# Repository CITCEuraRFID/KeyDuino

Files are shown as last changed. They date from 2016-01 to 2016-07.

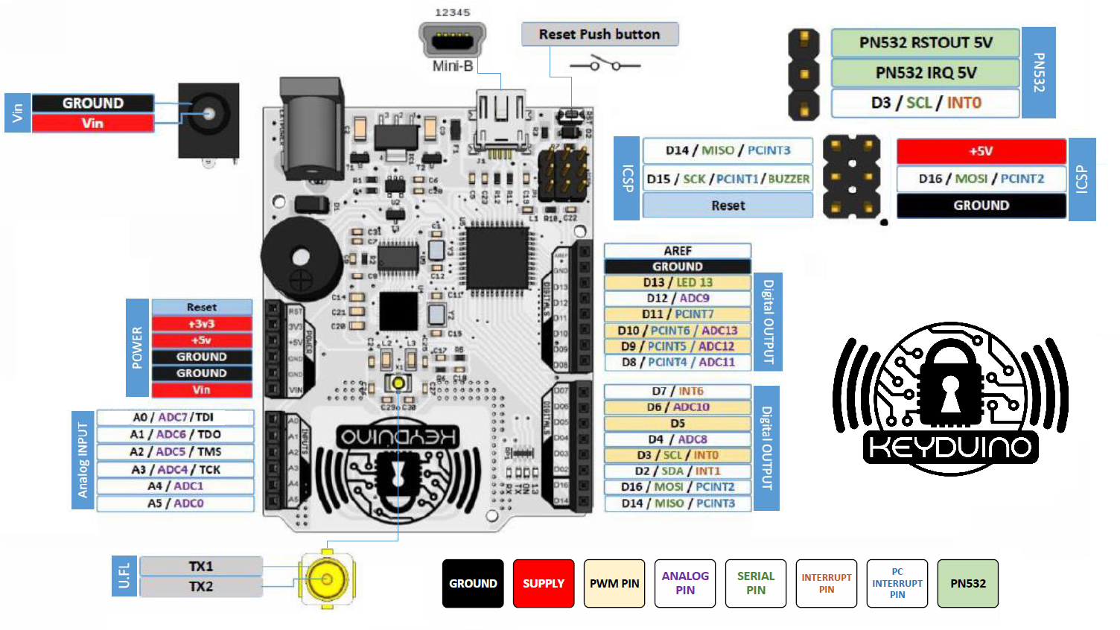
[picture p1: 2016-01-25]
hardware/KeyDuino_board/pinout KeyDuino 5.1/KeyDuino PINOUT.png

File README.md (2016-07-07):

## KeyDuino Library

Welcome to KeyDuino official GitHub repository!  
Here you will find all the files you need to develop programs for your KeyDuino.  
You can also look at the [wiki](https://github.com/CITCEuraRFID/KeyDuino/wiki) for informations about KeyDuino and its capabilities.  

The library is still under development, and everything is not perfect yet!  
That is why we would be very glad to hear from you about your experience with KeyDuino library ; if you encounter any problem, please feel free to open issues or contact us directly: that way we will be able to correct errors and improve the library.

### Tutorials & Projects
If you want to discover what you can do with your KeyDuino, join http://keyduino.forumsactifs.com/ !  
There you will find projects ideas, discussions, and tutorials, to help you get the best from your KeyDuino.  
If you have ideas to share, or questions to ask, don't hesitate! We would be very glad to hear from you.  

### Content
In this repository, you will find pretty much everything we develop for KeyDuino.

```
/---KeyDuino                  //The root folder of the repository  
|   +---KeyDuino              //The lib subfolder you need to put in your Arduino/libraries folder  
|   |   +---examples          //All the examples supplied within the lib  
|   |   |   +---projects      //Examples associated with KeyDuino projects  
|   |   |   +---NDEF          //Examples using the NDEF lib you need to download separately  
|   |   |   +---...  
|   |   |  
|   |   +---...  
|   |
|   +---KeyDuinoESP           //An implementation of KeyDuino with ESP module for WiFi communication  
|   |   +---ESP               //Files for the ESP  
|   |   +---KeyDuino          //Files for the KeyDuino  
|   |  
|   +---android_app           //The folder containing everything about Android application  
|   |   +---nfc_talker.apk    //The apk of the Android application we developped  
|   |    
|   +---hardware              //All hardware files of KeyDuino  
|   |   +---3D_printed_case   //STL files for 3D printed case
|   |   +---KeyDuino_board    //Hardware files for KeyDuino board  
|   |   +---antenna           //Hardware files for KeyDuino remote antenna  
```

### Compatibility
KeyDuino library is made to be used with [KeyDuino board](https://www.kickstarter.com/projects/1535978353/keyduino), but it also works by default with a classical Arduino Leonardo using a PN532 Shield, as long as communication is done through HSU.

### Contribution
KeyDuino library is based on Adafruit_NFCShield_I2C, with improvements by Seeed Studio, and HSU (High Speed Uart) driver added by Elechouse.

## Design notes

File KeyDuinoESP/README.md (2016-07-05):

# KeyDuinoESP
NFC enabled module in order to control authorized access via WiFi
- KeyDuino
- ESP-12

# Libraries used
- ESP8266: https://github.com/esp8266/Arduino
- MQTT: https://github.com/knolleary/pubsubclient
- KeyDuino: https://github.com/CITCEuraRFID/KeyDuino/tree/master/KeyDuino
- Streaming (print in C++): http://arduiniana.org/libraries/streaming/
- FastLED: https://github.com/FastLED/FastLED

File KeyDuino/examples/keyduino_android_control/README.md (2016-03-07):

## Dependency

This sketch is made to be used with KeyDuino mobile application, for demonstration purposes.  
It works with [bblanchon's ArduinoJson library](https://github.com/bblanchon/ArduinoJson/releases).  

If you encounter troubles using it with an older Arduino IDE version, [this ArduinoJson version](https://github.com/bblanchon/ArduinoJson/releases/download/v5.0.7/ArduinoJson-v5.0.7-old-layout.zip) may work better.  

Please note that you don't need this for NFC P2P in general ; we simply decided to use JSON to ease communication of pin numbers, etc.

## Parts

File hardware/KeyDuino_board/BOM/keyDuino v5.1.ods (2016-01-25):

Part | QTY | Value | Device | Package | Description | REF | REF ELECROW | REMARQUE
CAPACITOR
C1, C11, C12, C15 | 4 | 22pF | C-EUC0603 | C0603 | Capacitor | capacitor 0603 22pF | 2010822A
C24, C25 | 2 | 220pF | C-EUC0603 | C0603 | Capacitor | capacitor 0603 220pF
C26, C27 | 2 | 2200pF | C-EUC0603 | C0603 | Capacitor | capacitor 0603 2200pF
C18 | 1 | 1nF | C-EUC0603 | C0603 | Capacitor | capacitor 0603 1nF | 2011501A
C29, C30 | 2 | 1,2nF | C-EUC0603 | C0603 | Capacitor | Capacitor 0603 1,2nF
C5, C7, C8, C17, C22, C28, C31 | 7 | 100nF | C-EUC0603 | C0603 | Capacitor | capacitor 0603 100nF | 2013010A
C6, C9, C19, C23 | 4 | 1uF | C-EUC0603 | C0603 | Capacitor | capacitor 0603 1uF | 2013501A
C21 | 1 | 100nF | C-EUC0805 | C0805 | Capacitor | capacitor 0805 100nF
C14, C20 | 2 | 10uF | C-EUC0805 | C0805 | Capacitor | capacitor 0805 10uF | 2015010A
C2 | 1 | 10uF | CPOL-EUSMCB | SMC_B 1206 | CAPACITOR | SMC_B 1206 10uF
C3 | 1 | 22uF | CPOL-EUSMCB | SMC_B 1206 | CAPACITOR | SMC_B 1206 22uF
RESISTOR
R11, R12 | 2 | 22 | R-EU_R0603 | R0603 | RESISTOR | RESISTOR 0603 22 | 1020522A
R5 | 1 | 1.0K | R-EU_R0603 | R0603 | RESISTOR | RESISTOR 0603 1K | 1022501A
R6 | 1 | 2.7K | R-EU_R0603 | R0603 | RESISTOR | RESISTOR 0603 2,7K
R1, R2, R4, R7, R10 | 5 | 10K | R-EU_R0603 | R0603 | RESISTOR | RESISTOR 0603 10K | 1023510A
R3 | 1 | 1M | R-EU_R0805 | R0805 | RESISTOR | RESISTOR 0805 1M
RP1 | 1 | 330 | RES4NT | RES4NT | 4 Resistor Array | 4 Resistor Array 330
INDUCTOR
L1 | 1 | MH2029-300Y | WE-CBF_0805 | 805 | SMD EMI Ferrite | MH2029-300Y
L2, L3 | 2 | 560nH | INDUCTOR0805 | 0805@1 | Inductors | inductor 560nH 0805
DIODE & FUSE
D1 | 1 | M7 | DIODE-SMB | SMB | DIODE | SMB M7 (leonardo)
D2 | 1 | CD1206-S01575 | DIODE-MINIMELF | MINIMELF | DIODE | CD1206-S01575
F1 | 1 | 500mA | PTCSMD | PTC-1206 | Resettable Fuse PTC | FUSE 0805 500mA | 4060505A
CONNECTOR & MECHANICAL
ICSP | 1 | ICSP | PINHD-2X3 | 2X03 | PIN HEADER |  | 6031123A | TO SOLDER
JP1 | 1 |  | PINHD-1X3 | 1X03 | PIN HEADER |  | 6030916A | TO SOLDER
JP2 | 1 |  | PINHD-1X8CLEANBIG | 1X08-CLEANBIG | PIN HEADER |  | 6030618A | TO SOLDER
JP3 | 1 |  | PINHD-1X8CLEANBIG | 1X08-CLEANBIG | PIN HEADER |  | 6030618A | TO SOLDER
JP4 | 1 |  | PINHD-1X6CB | 1X06-CLEANBIG | PIN HEADER |  | 6030516A | TO SOLDER
JP6 | 1 |  | PINHD-1X6CB | 1X06-CLEANBIG | PIN HEADER |  | 6030516A | TO SOLDER
X1 | 1 |  | ANTENNA_U.FL | U.FL | U.FL Antenna Connector | u.FL connector | 6021031A
J1 | 1 | USB-MINI-B%C | USB-MINI-B%C | USB-MINI-B_2 |  | arduino LEONARDO | 6020522B
EXTPOWER | 1 | POWERSUPPLY_DC21MMX | POWERSUPPLY_DC21MMX | DC-21MM |  | arduino LEONARDO | 6011021A
RST | 1 | RESET | PB157 | 157SW | SKRKAEE010 | 157SW | 7020890A
BUZZ | 1 | F/QMX | F/QMX | F/QMX |  | F/QMX (3,3v) |  | TO SOLDER
LEDs
RX | 1 |  | LEDCHIPLED_0603 | CHIPLED_0603 | LED | 0603 LED yellow | 4040606A
TX | 1 |  | LEDCHIPLED_0603 | CHIPLED_0603 | LED | 0603 LED RED | 4040506A
ON | 1 |  | LEDCHIPLED_0603 | CHIPLED_0603 | LED | 603 LED green | 4040706A
13 | 1 |  | LEDCHIPLED_0603 | CHIPLED_0603 | LED | 603 LED blue | 4040806A
IC
U1 | 1 | ATMEGA32U4-XUAU | ATMEGA32U4-XUAU | TQFP44-PAD | ATMEGA32U4-XUAU | ATMEGA32U4-XUAU
U2 | 1 | LP2985-33DBVR | LP2985-XXDBVR33 | SOT23-DBV | ULTRALOW-POWER REGULATORS | LP2985-33DBVR
IC1 | 1 | NCP1117ST50T3G | MC33269ST-3.3T3 | SOT223 | Regulator 800 mA | NCP1117ST50T3G |  | 117-5
U3 | 1 |  | TXB0108PWR | TSSOP20 | 8-Bit Bi-Directional Level Shifter | TXB0108PWR
U4 | 1 | PN532 | PN532 | HVQFN40-6X6 | PN532 - Near Field Communication (NFC) controller | PN532
CRYSTAL
Y2 | 1 | 27.12MHz | CRYSTALTHIN | CRYSTAL_3.2X2.5 | Crystals | 7B-27,1200MAAJ-T
Y3 | 1 | 16MHz KX-7 | CRYSTAL-3.2-2.5 | CRYSTAL-3.2-2.5 |  | 16MHz KX-7
MOSFET
T1 | 1 | PMV48XP | PMOSSOT23 | SOT-23 | MOS FET | PMV48XP
T2 | 1 | FDN340P | PMOSSOT23 | SOT-23 | MOS FET | FDN340P
T3 | 1 | BSS123 | PMOSSOT23 | SOT-23 | MOS FET | BSS123
CABLE USB MINI MALE
2 x 2,54mm jumpers

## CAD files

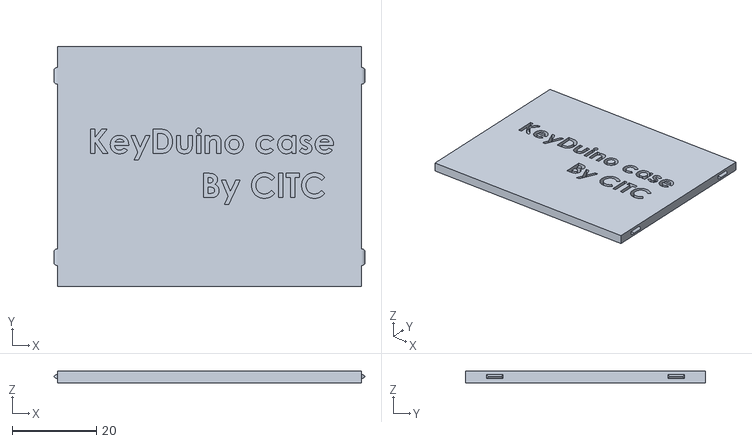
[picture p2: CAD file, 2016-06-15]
hardware/3D_printed_case/charlier_case/top KeyDuino case.STL
73.7 x 57.0 x 2.80

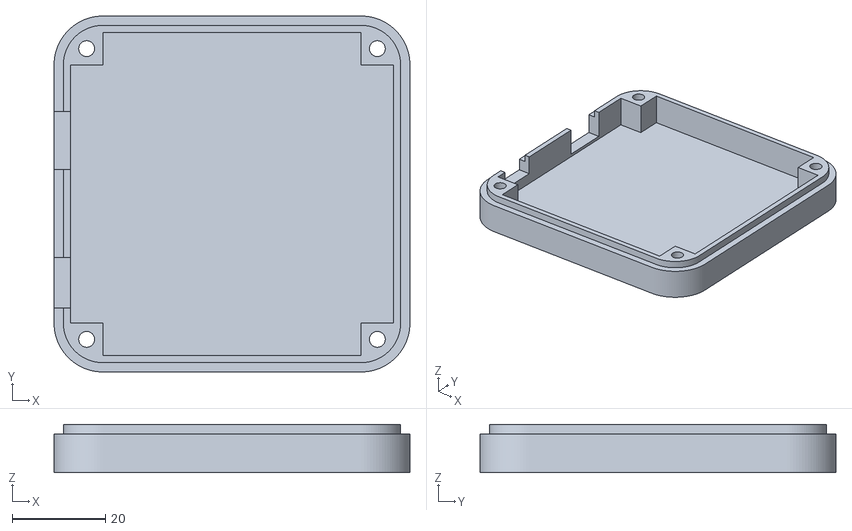
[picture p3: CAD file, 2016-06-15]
hardware/3D_printed_case/ray_case/leonardo_case_base_v1_2_ray_bin.stl
76.3 x 76.3 x 10.3

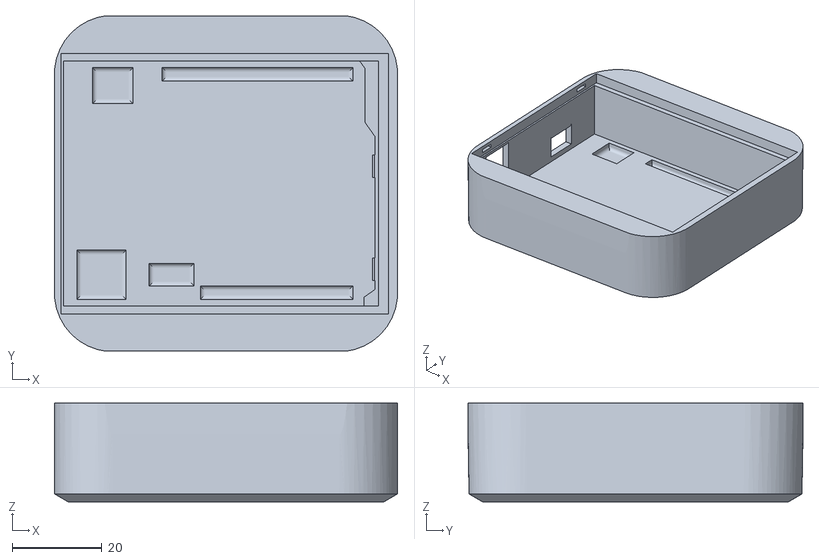
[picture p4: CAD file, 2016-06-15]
hardware/3D_printed_case/charlier_case/KeyDuino case5.STL
76.5 x 74.6 x 22.0

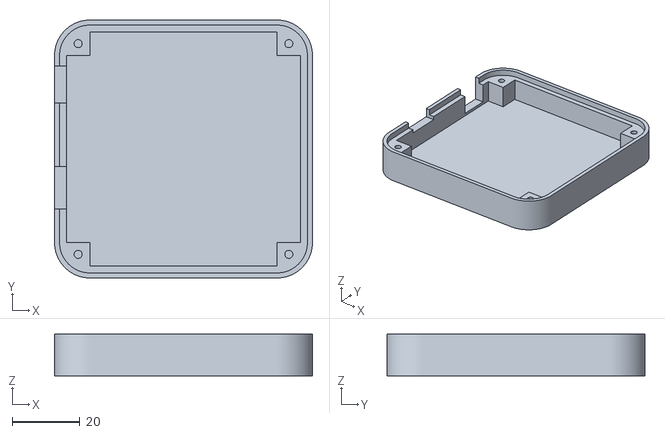
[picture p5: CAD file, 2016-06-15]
hardware/3D_printed_case/ray_case/leonardo_case_lid_v1_2_ray.stl
76.3 x 76.3 x 12.3

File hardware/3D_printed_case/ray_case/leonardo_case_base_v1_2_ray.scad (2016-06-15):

//  ----------------------------------------------------------------------- LICENSE
//  This "3D Printed Case for Arduino Uno, Leonardo" by Zygmunt Wojcik is licensed
//  under the Creative Commons Attribution-ShareAlike 3.0 Unported License.
//  To view a copy of this license, visit
//  http://creativecommons.org/licenses/by-sa/3.0/
//  or send a letter to Creative Commons, PO Box 1866, Mountain View, CA 94042, USA.


include <leonardo_case_param_v1_2.scad>

//------------------------------------------------------------------------- MODULES
module pcbLeg() {		
	translate([0, 0, 0])
	difference() { 											
		cylinder(h = floorHeight + pcbPositionZ, r1=5.5/2, r2 = 4.5/2);
	}
}


//------------------------------------------------------------------------- MAIN BLOCK
difference()
{
																		// ADD
	union()
	{
		// Add Base
		linear_extrude(height = height/2, convexity = 10)
		minkowski()
		{									
			square([width, wide], center = true);
			circle(roundR);
		}
	}
																		// SUBSTRACT
	union()
	{
		// Lift floor height
		translate([0, 0, floorHeight])
		{
			// Cut Base hole
			linear_extrude(height = height/2, convexity = 10)
			minkowski()
			{
				square([width, wide], center = true);
				circle(roundR - pillarSize);
			}
			// Cut upper block lock
			difference() {
				translate([0, 0, height/2 - floorHeight - blockLockSize]) {
					cylinder(h = blockLockSize+gap, r=width);
				}
				translate([0, 0, height/2 - floorHeight - blockLockSize - gap*2]) {
					linear_extrude(height = blockLockSize+gap*4, convexity = 10)
					minkowski() {
						square([width, wide], center=true);
						circle(roundR - layerWidth*4);
					}
				}
			}
			// Cut x panels 
			for (i = [0 : 180 : 180])				
			rotate([0, 0, i])
			translate([width/2 + roundR - pillarSize/2 - layerWidth*7, 0, 0])
			{
				// Cut X panel hole
				translate([0, 0, height/2])
				cube([pillarSize, sidePanelXWidth, height], center=true);
                
				// Cut X, Y srew holes
				for (i = [wide/2, -wide/2])
				{
					translate([-(roundR - pillarSize/2 - layerWidth*7), i, - floorHeight])
					if (i>0) 
					{
						rotate([0, 0, 45])
						translate([screwHoleRoundR, 0, 0])
						{
							cylinder(h = height*2, r=screwExt/2, center=true);
							cylinder(h = 5,
                                    r1 = (screwHead + (screwHead - screwExt))/2,
                                    r2 = screwExt/2, center=true);
						}
					}
					else
					{
						rotate([0, 0, -45])
						translate([screwHoleRoundR, 0, 0])
						{
							cylinder(h = height*2, r=screwExt/2, center=true);
							cylinder(h = 5,
                                    r1 = (screwHead + (screwHead - screwExt))/2,
                                    r2 = screwExt/2, center=true);
						}
					}
				}
			}
			// Cut Y panels 
			for (i = [90 : 180 : 270])
			rotate([0, 0, i])
			translate([wide/2 + roundR - pillarSize/2 - layerWidth*7, 0, 0])
			{
				// Cut Y panel hole
				translate([0, 0, height/2])
				cube([pillarSize, sidePanelYWidth, height], center=true);
			}
			
            // Cut USB and Power holes
			// translate to pcb position
			translate([-pcbPositionX, -pcbWide/2, pcbPositionZ + pcbHeight])
			{
				// cut power hole
				translate([0, powerJackPosition, (powerJackHeight-2)/2])
				cube([10, powerJackWide, powerJackHeight], center=true);
				// cut usb hole
				translate([0, usbHolePosition, 1.3])
				cube([10, usbWide, usbHeight], center=true);
			}
		}
	}
}
//------------------------------------------------------------------------- ADD PCB LEGS
// Translate to pcbPositionX	
translate([-pcbPositionX, -pcbWide/2, 0])

difference()
{
																		// ADD
	union()
	{
		
	}
																		// SUBSTRACT
	union()
	{
		//
	}
}

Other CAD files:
hardware/3D_printed_case/ray_case/leonardo_case_lid_v1_2_ray.scad

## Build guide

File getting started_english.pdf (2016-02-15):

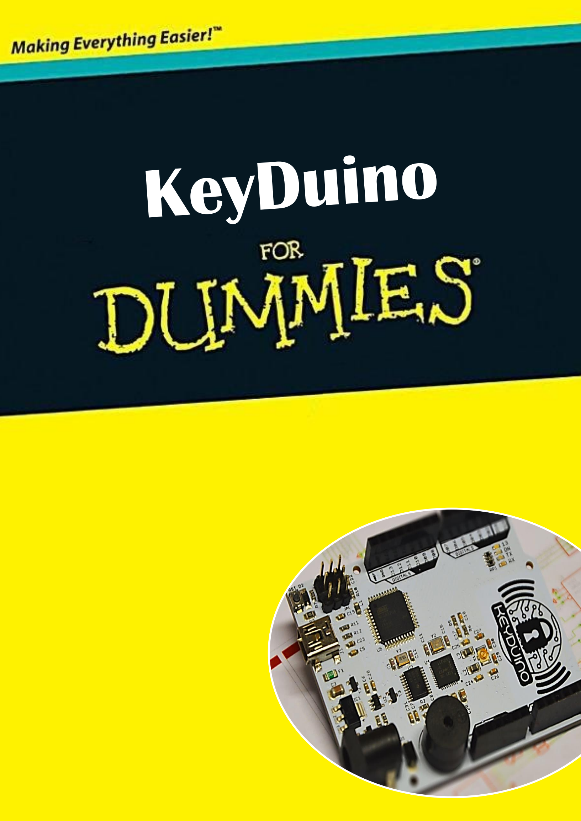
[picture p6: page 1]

## Introduction

KeyDuino is a NFC development platform which allows quick and easy creation of prototypes. This card is not a finished product for a defined application but can be adapted to different projects while adding specific material equipment and security software.

Therefore, you should pay attention to the liability and protection of your own developments on the platform. They are utterly under your responsibility, and so is the usage of the application you will develop.

This document provides key points you will need to realize your projects.

KeyDuino is a powerful tool and we all must ensure that its use respects the values that led to its creation. By this we mean the values of a community of geeks/makers but also responsible people aiming at developing and sharing innovative projects, competences and good ideas.

Hence, don’t forget that hacking attempts on systems that don’t belong to you are against the spirit of KeyDuino. Moreover, remember that alone we are faster, but together we go further!

### KeyDuino Team

# 1) Initialize your KeyDuino

### Install Arduino environment

To start using and program your KeyDuino, you require the Arduino development environment (IDE). You may download it there:
https://www.arduino.cc/en/Main/Software Current developments are made under Arduino version 1.6.5. If you are a new Arduino developer, we advise you to use that same version to avoid troubles.
Unzip the file and install Arduino.

### Download KeyDuino library

To get access to KeyDuino code samples and library, you first have to download it on GitHub platform:
https://github.com/CITCEuraRFID/KeyDuino Click the « Download ZIP » button, and once the download is complete, extract it. In KeyDuino directory, you will find different folders. Simply copy the KeyDuino subfolder and paste it in your Arduino libraries directory. The library is now installed! You can then start Arduino IDE and use it.

### Getting KeyDuino Android application

We have developed an Android application to experiment exchanges with smartphones. You can find the APK file in KeyDuino directory.
We will soon add the sources in the GitHub repository too.
Remind yourself that current Apple iPhones are not compatibles with KeyDuino or NFC tags.

### Install KeyDuino drivers

Connect KeyDuino board to your computer with the supplied cable. « On » LED should light.

- Windows
For Microsoft Windows :
http://www.visualmicro.com/post/2012/06/02/Arduino-Leonardo-Windows-Hardware-USB-Installation-Guide.aspx (http://www.visualmicro.com/post/2012/06/02/Arduino-Leonardo-Windows-Hardware-USB-Installation-Guide.aspx)
- Linux
Connect the board. That's all.
- Mac OS
The first time you connect the board on a Mac OS system, the « Keyboard Setup Assistant » should open. Just shut the window, you don't have anything to configure.

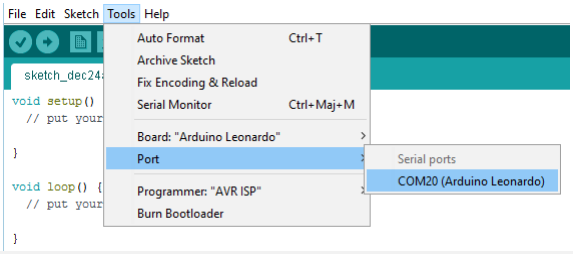
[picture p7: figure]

Error : you’re getting the following error message

Check if selected com port is still the same. Sometimes, the port disconnect and change. Then try again. If the problem persists, disconnect the board, shut the monitor, reconnect the board and retry.

Error: the port isn't detected

Solution 1: Disconnect your KeyDuino, close the IDE. Reconnect the board and retry selecting the port. Solution 2 : Re-install the drivers, and check if KeyDuino is recognized by your computer.

# 2) Get started with your KeyDuino

### Identify a tag

In the IDE, select the port your board is plugged to. The board should be identified as a Arduino Leonardo.

Hopefully, the default sketch on the board will allow to read NFC tags and display its ID. To get the informations, click on « Serial Monitor » button.

For this example, your selected baudrate must be 115200 Bauds. By default, if you just downloaded the IDE, it will probably be 9600 ; just change it in the Serial Monitor. Now, take the supplied NFC tag and approach it from KeyDuino antenna ; you should hear a « bip » sound when the board detects it.

Reading antenna

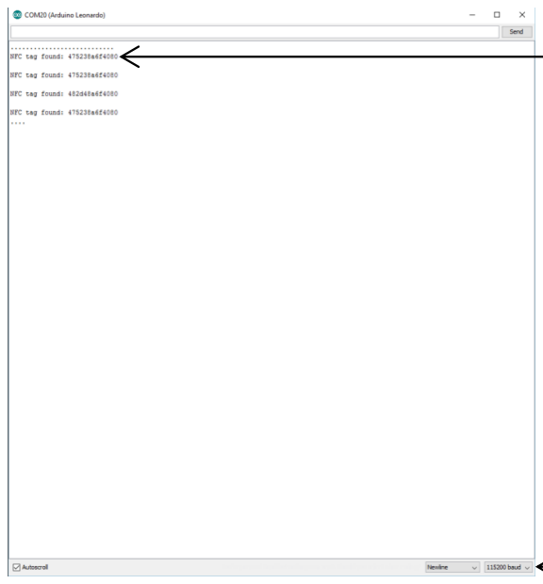
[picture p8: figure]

Error: nothing happens

Solution 1: Try with the other tag. Si that one is working, please contact us for replacement of the deficient tag. Solution 2: Take away KeyDuino board from any metallic surface during reading.
Solution 3: Try with example PN532_TEST ; if you hear no sound, please contact us (). If you hear a sound, try programming the board with tag_identification example (see below).

### (Optionnal) Connecting the antenna

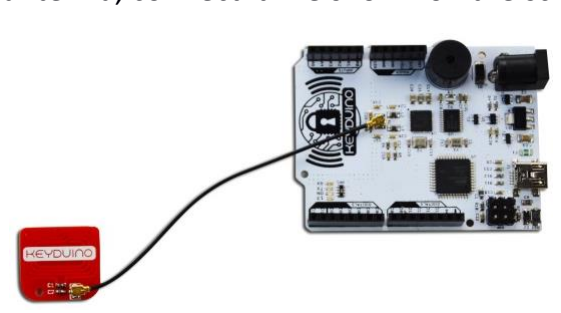
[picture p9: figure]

If you ordered a separate antenna, connect it like shown on the schematic below. You should hear a « click ».

### You are now ready to use your KeyDuino!

Baudrate

Tag ID

Advice:

- Try to not bend the cable
- Don't connect and disconnect the cable too often for it is quite fragile. Take care of it.
- Avoid putting it through metallic material
- Like integrated antenna, do not put it in contact with metal
- Use plastic screws rather than metallic ones to fix the antenna
- Note that superglue and double-sided tape work fine!

# Annexe 1 : schematics

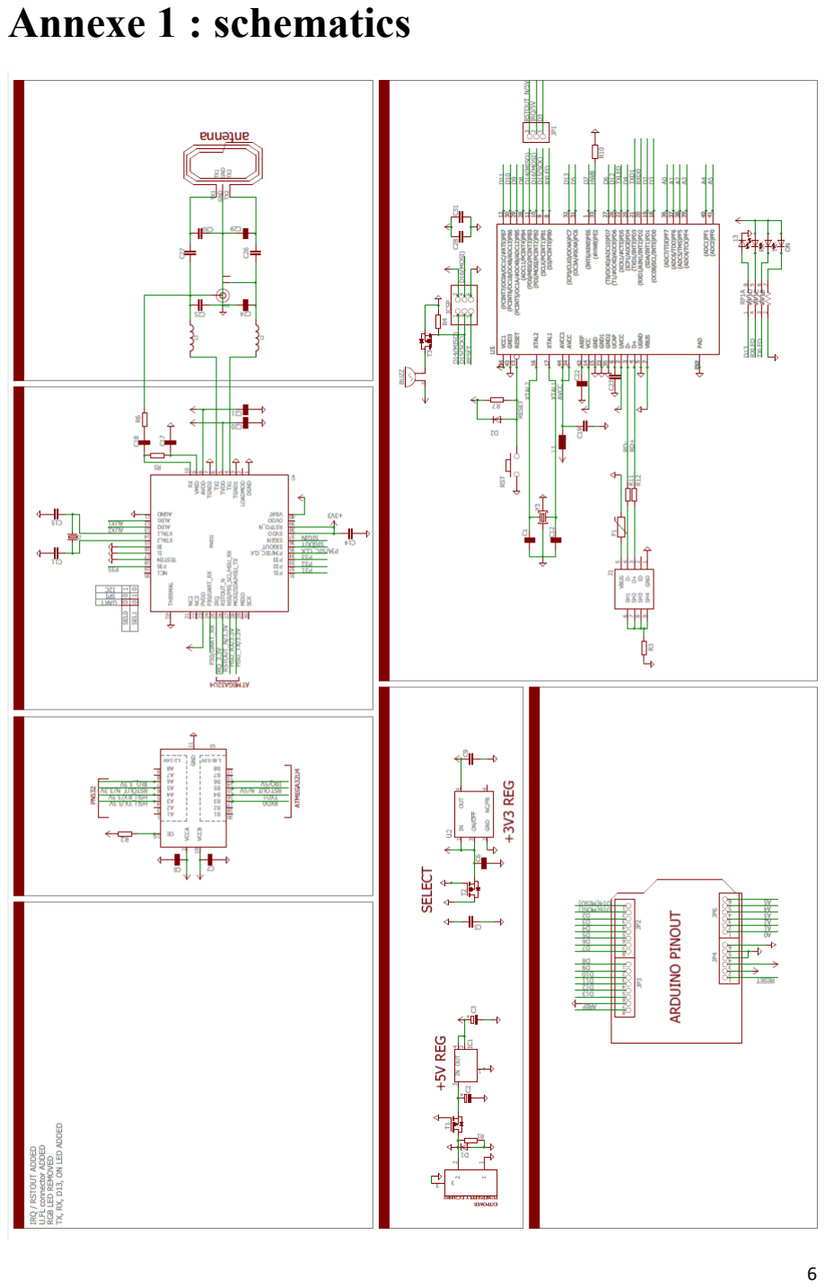
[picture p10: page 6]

# Annexe 2 : layout

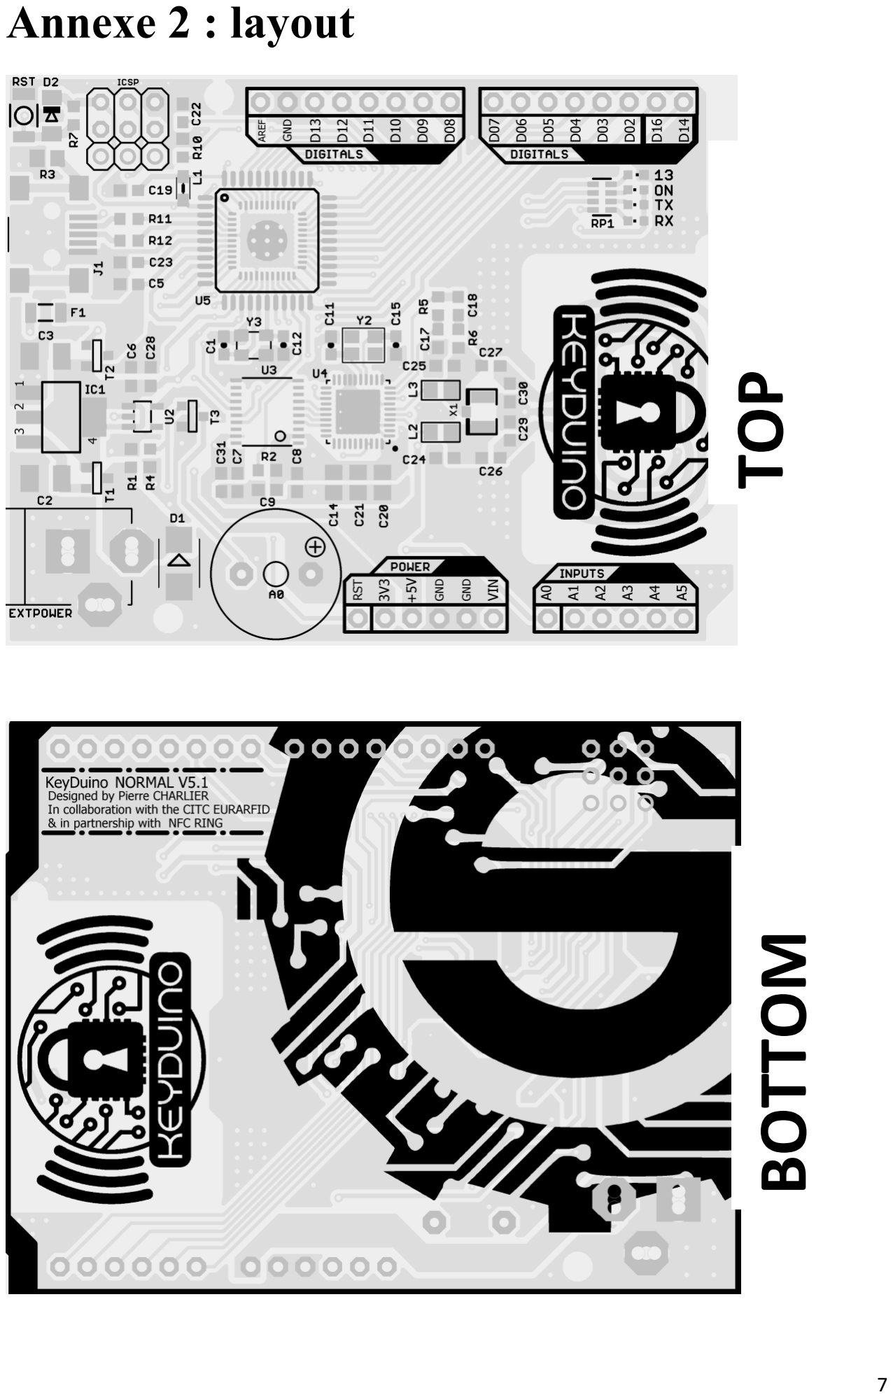
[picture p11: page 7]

# TOP BOTTOM

# Annexe 3 : BOM (Bill Of Material)

Part | QTY | Value | Device | Package | Description | REF

CAPACITOR

C1, C11, C12, C15 | 4 | 22pF | C-EUC0603 | C0603 | Capacitor | capacitor 0603 22pF
C24, C25 | 2 | 220pF | C-EUC0603 | C0603 | Capacitor | capacitor 0603 220pF
C26, C27 | 2 | 2200pF | C-EUC0603 | C0603 | Capacitor | capacitor 0603 2200pF
C18 | 1 | 1nF | C-EUC0603 | C0603 | Capacitor | capacitor 0603 1nF
C29, C30 | 2 | 1,2nF | C-EUC0603 | C0603 | Capacitor | Capacitor 0603 1,2nF
C5, C7, C8, C17, C22, C28, C31 | 7 | 100nF | C-EUC0603 | C0603 | Capacitor | capacitor 0603 100nF
C6, C9, C19, C23 | 4 | 1uF | C-EUC0603 | C0603 | Capacitor | capacitor 0603 1uF
C21 | 1 | 100nF | C-EUC0805 | C0805 | Capacitor | capacitor 0805 100nF
C14, C20 | 2 | 10uF | C-EUC0805 | C0805 | Capacitor | capacitor 0805 10uF
C2 | 1 | 10uF | CPOL-EUSMCB | SMC_B 1206 | CAPACITOR | SMC_B 1206 10uF
C3 | 1 | 22uF | CPOL-EUSMCB | SMC_B 1206 | CAPACITOR | SMC_B 1206 22uF

RESISTOR

R11, R12 | 2 | 22 | R-EU_R0603 | R0603 | RESISTOR | RESISTOR 0603 22
R5 | 1 | 1.0K | R-EU_R0603 | R0603 | RESISTOR | RESISTOR 0603 1K
R6 | 1 | 2.7K | R-EU_R0603 | R0603 | RESISTOR | RESISTOR 0603 2,7K
R1, R2, R4, R7, R10 | 5 | 10K | R-EU_R0603 | R0603 | RESISTOR | RESISTOR 0603 10K
R3 | 1 | 1M | R-EU_R0805 | R0805 | RESISTOR | RESISTOR 0805 1M
RP1 | 1 | 330 | RES4NT | RES4NT | 4 Resistor Array | 4 Resistor Array 330

INDUCTOR

L1 | 1 | MH2029-300Y | WE-CBF_0805 | 805 | SMD EMI Ferrite | MH2029-300Y
L2, L3 | 2 | 560nH | INDUCTOR0805 | 0805@1 | Inductors | inductor 560nH 0805

DIODE & FUSE

D1 | 1 | M7 | DIODE-SMB | SMB | DIODE | SMB M7 (leonardo)
D2 | 1 | CD1206-S01575 | DIODE-MINIMELF | MINIMELF | DIODE | CD1206-S01575
F1 | 1 | 500mA | PTCSMD | PTC-1206 | Resettable Fuse PTC | FUSE 0805 500mA

CONNECTOR & MECHANICAL

ICSP | 1 | ICSP | PINHD-2X3 | 2X03 | PIN HEADER
JP1 | 1 | | PINHD-1X3 | 1X03 | PIN HEADER
JP2 | 1 | | PINHD-1X8CLEANBIG | 1X08-CLEANBIG | PIN HEADER
JP3 | 1 | | PINHD-1X8CLEANBIG | 1X08-CLEANBIG | PIN HEADER
JP4 | 1 | | PINHD-1X6CB | 1X06-CLEANBIG | PIN HEADER
JP6 | 1 | | PINHD-1X6CB | 1X06-CLEANBIG | PIN HEADER
X1 | 1 | | ANTENNA_U.FL | U.FL | U.FL Antenna Connector | u.FL connector
J1 | 1 | USB-MINI-B%C | USB-MINI-B%C | USB-MINI-B_2
EXTPOWER | 1 | POWERSUPPLY_DC21MMX | POWERSUPPLY_DC21MMX | DC-21MM
RST | 1 | RESET | PB157 | 157SW | SKRKAEE010 | 157SW
BUZZ | 1 | F/QMX | F/QMX | F/QMX | | F/QMX (3,3v)

LEDs

RX | 1 | LEDCHIPLED_0603 | CHIPLED_0603 | LED | 0603 LED yellow
TX | 1 | LEDCHIPLED_0603 | CHIPLED_0603 | LED | 0603 LED RED
ON | 1 | LEDCHIPLED_0603 | CHIPLED_0603 | LED | 603 LED green
13 | 1 | LEDCHIPLED_0603 | CHIPLED_0603 | LED | 603 LED blue

IC

U1 | 1 | ATMEGA32U4-XUAU | ATMEGA32U4-XUAU | TQFP44-PAD | ATMEGA32U4-XUAU | ATMEGA32U4-XUAU
U2 | 1 | LP2985-33DBVR | LP2985-XXDBVR33 | SOT23-DBV | ULTRALOW-POWER REGULATORS | LP2985-33DBVR
IC1 | 1 | NCP1117ST50T3G | MC33269ST-3.3T3 | SOT223 | Regulator 800 mA | NCP1117ST50T3G
U3 | 1 | | TXB0108PWR | TSSOP20 | 8-Bit Bi-Directional Level Shifter | TXB0108PWR
U4 | 1 | PN532 | PN532 | HVQFN40-6X6 | PN532 – NFC controller | PN532

CRYSTAL

Y2 | 1 | 27.12MHz | CRYSTALTHIN | CRYSTAL_3.2X2.5 | Crystals | 7B-27,1200MAAJ-T
Y3 | 1 | 16MHz KX-7 | CRYSTAL-3.2-2.5 | CRYSTAL-3.2-2.5 | | 16MHz KX-7

MOSFET

T1 | 1 | PMV48XP | PMOSSOT23 | SOT-23 | MOS FET | PMV48XP
T2 | 1 | FDN340P | PMOSSOT23 | SOT-23 | MOS FET | FDN340P
T3 | 1 BSS123 | PMOSSOT23 | SOT-23 | MOS FET | BSS123

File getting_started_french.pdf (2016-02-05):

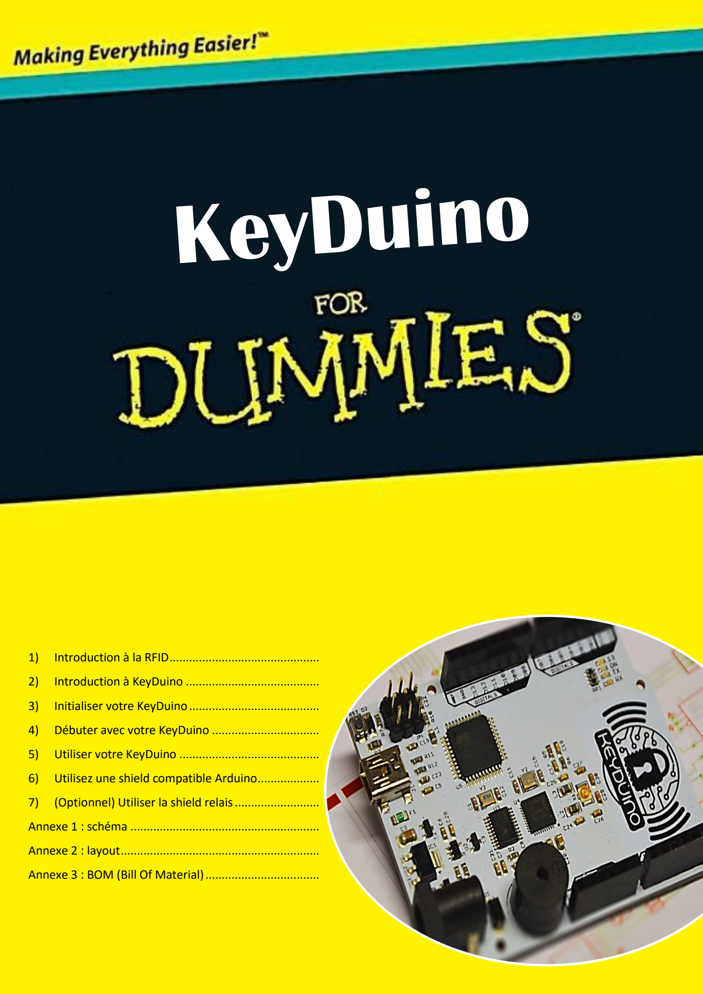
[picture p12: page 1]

1) Introduction à la RFID |
2) Introduction à KeyDuino |
3) Initialiser votre KeyDuino |
4) Débuter avec votre KeyDuino |
5) Utiliser votre KeyDuino |
6) Utilisez une shield compatible Arduino |
7) (Optionnel) Utiliser la shield relais |
Annexe 1 : schéma |
Annexe 2 : layout |
Annexe 3 : BOM (Bill Of Material) |

## Avertissements

KeyDuino est une plateforme de développement NFC qui permet de créer facilement et rapidement des prototypes. Cette carte ne consiste pas en un produit terminé pour telle ou telle application et nécessite en fonction du projet à réaliser d’y ajouter des équipements matériels ou logiciels à sécuriser

À ce titre, la question de la fiabilité et de la protection de vos développements à partir de la plateforme est importante et est de votre entière responsabilité, au même titre que l’usage des applications que vous développerez.

Par ce document, nous vous apportons quelques clefs nécessaires au bon fonctionnement de vos projets.

KeyDuino peut être un outil puissant, c’est pourquoi il nous revient collectivement de respecter, lors de son utilisation, les valeurs qui ont mené à sa création : la création d’une communauté de bidouilleurs/geeks/passionnés et surtout responsables s’attachant à développer des projets sympathiques, à partager les compétences et bonnes idées

Dès lors, n’oubliez pas que les tentatives de hack sur des systèmes ne vous appartenant pas vont à l’encontre de « l’état d’esprit KeyDuino ». et que seul on va plus vite mais ensemble, on va plus loin !

### KeyDuino Team

# 1) Introduction à la RFID

### Présentation globale

La RFID (Radio Frequency Identification) est une technologie bien implantée dans de nombreux secteurs. Cette technologie existe depuis les années 1970, mais s'est surtout développée à la fin des années 1990.

Les systèmes utilisant la RFID sont composés de deux parties : un lecteur, qui va venir apporter l’énergie, et un transpondeur (un tag).
Ces derniers communiquent par liaison radio fréquences.

On distingue 3 catégories d’applications :
- La RFID LF (Low Frequency) : de 125 à 135 kHz et ayant une portée de moins de 10 centimètres. Elle est principalement utilisée dans les badges d’accès.
- La RFID HF (High Frequency) : sur une fréquence de 13,56 MHz. La RFID HF est notamment utilisée dans les passeports biométriques et sert de base à la technologie NFC (Near Field Communication) présente dans de très nombreux produits.
- La RFID UHF (Ultra High Frequency): en Europe, sa fréquence est de 868 MHz. La portée est étendue à une dizaine de mètres. Cette technologie est notamment utilisée pour la traçabilité en logistique, ainsi que pour dresser des inventaires.

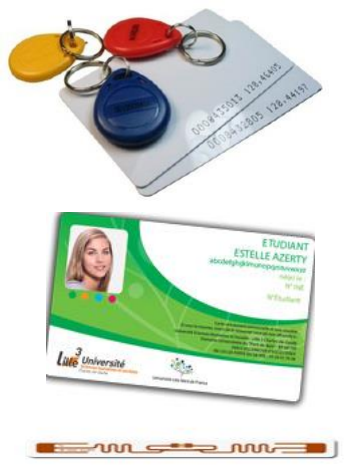
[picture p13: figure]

La structure d’un transpondeur est extrêmement simple. Il s’agit uniquement d’une antenne reliée à une puce.

Le lecteur se couple au transpondeur et envoie de l’énergie au transpondeur dont le processeur est alors alimenté.
Dans ce document, nous parlerons uniquement de tags passifs (non alimentés de

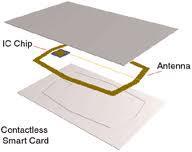
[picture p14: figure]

façon interne).

En termes de couplage, il en existe deux types;
- le couplage magnétique (H) dans le cas d’un champ dit proche (de quelques centimètres à 1.5m). Les fréquences utilisées sont les LF et HF. Les antennes sont alors constituées de boucles inductives.
- le couplage électrique (E) pour le champ dit lointain (jusqu’à 6 mètres).
Les fréquences en jeux sont l’UHF. Les antennes sont alors des dipôles ou des patchs.

### La NFC

La NFC, ou Near Field Communication (Communication en Champ Proche), est une technologie standardisée de communication sans-fil à courte portée, permettant des transactions, de l'échange de données numériques, et la connexion d'appareils électroniques par un simple contact. La NFC est compatible avec des centaines de millions de smartphones, cartes sans-contact, et lecteurs déjà déployés dans le monde entier.

# 2) Introduction à KeyDuino

### Généralités sur KeyDuino

KeyDuino est une carte électronique programmable utilisant l’environnement Arduino (une plateforme de développement open source) et permettant de créer des interactions avec la technologie NFC.
Il est possible d’imaginer de nombreux scénarios d’utilisation des cartes KeyDuino dans de multiples domaines (transfert d’informations par NFC, identification sur une chaine de production,…). :

L’objectif principal de KeyDuino est de proposer une solution de prototypage rapide, plus spécifiquement dans le domaine de la sécurité. En effet, grâce aux nombreuses entrées sorties (E/S) dont disposent les cartes, connecter un actionneur, mécanique par exemple, est une chose facile. Dès lors, interagir sur une gâche de fermeture de porte, un verrou électronique, un starter de voiture, (…), est possible.
La technologie NFC prend tout son intérêt dans ce type d’applications. La lecture en champs proche permet d’opter pour une identification par carte, par badge et surtout via une bague NFC ou un smartphone.

### Architecture globale de KeyDuino

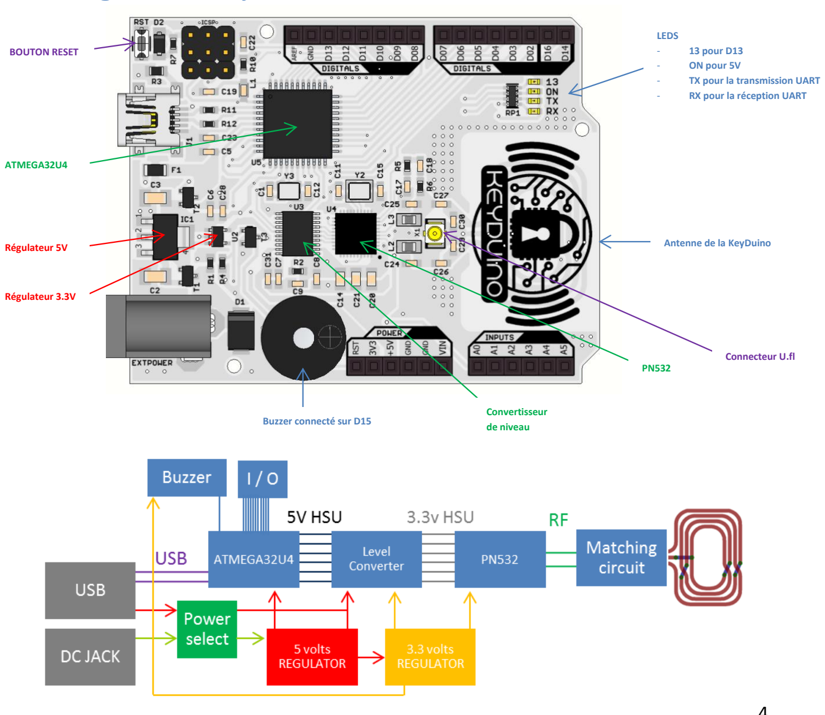
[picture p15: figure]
LEDS - 13 pour D13 - ON pour 5V - TX pour la transmission UART - RX pour la réception UART; Antenne de la KeyDuino; Buzzer connecté sur D15; ATMEGA32U4; Convertisseur de niveau; Connecteur U.fl; BOUTON RESET; Régulateur 5V; Régulateur 3.3V

### Pinout de KeyDuino

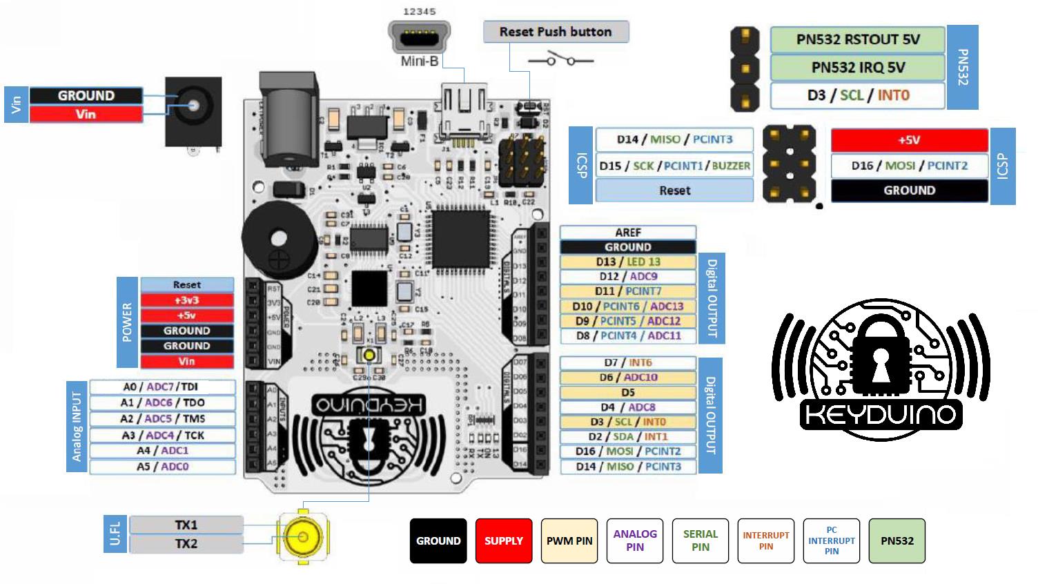
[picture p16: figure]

Alimentations
- Alimentation 5v
- Alimentation 3.3v
- Entrée d’alimentation VIN (pin ou connecteur)
- Sélection automatique entre VIN et l’alimentation 5volts Entrée/sorties
- 21 entrées sorties utilisables (A0-A5 & D2/D15)
- 7 PWM (D3, D5, D6, D9, D10, D11, D13)
- 12 entrées (A0-A5 & D4, D6, D8, D9, D10, D12) Communications
- Software UART
- Software SPI
- I2C
Processeur
- ATMEGA32U4
- mémoire flash disponible : 28KB
- SRAM : 2.5KB
- EEPROM : 1KB
- Fréquence 16Mhz
NFC
- PN532 connecté en HSU
- IRQ accessible
- RSTOUT accessible
- Connecteur U.fl lié à TX1, TX2

### Fréquence en jeu

Connaitre la fréquence de fonctionnement de KeyDuino va vous permettre de comprendre quel type de tags la carte pourra lire et ceux avec lesquelsi il sera impossible de communiquer.

Pour ce faire, observons un peu la forme de l’antenne de la KeyDuino :

Comme vous pouvez le constater, il s’agit d’une bobine constituée d’un ensemble de boucles inductives (4 boucles). KeyDuino utilise donc (principalement) le champ magnétique E pour communiquer avec les tags en champ proche.
Pour préciser, l’antenne de KeyDuino et son circuit d’accord sont calibrés pour une fréquence de 13.56Mhz, soit la fréquence de la RFID HF (excluant de fait la lecture de tags LF ou UHF).

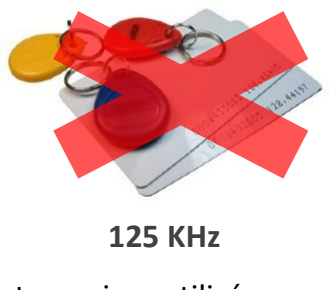
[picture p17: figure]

Le tranceiver utilisé pour permettre la lecture des tags est un PN532 connecté en HSU (High Speed Uart). Ce module supporte 7 modes d’opérations différents :

- ISO/IEC 14443A/MIFARE Reader/Writer
- FeliCa Reader/Writer
- ISO/IEC 14443B Reader/Writer
- ISO/IEC14443A/MIFARE Card MIFARE Classic 1K
- MIFARE Classic 4K card emulation mode
- FeliCa Card emulation
- ISO/IEC 18092, ECMA 340 Peer-to-Peer

### Métal et KeyDuino

Le champ magnétique de la NFC ne peut fonctionner à travers le métal. Par conséquent, il est impossible de lire un tag à travers n’importe quel élément métallique via la KeyDuino ou une antenne déportée.

125 KHz | 13.56 MHz | 868 MHz

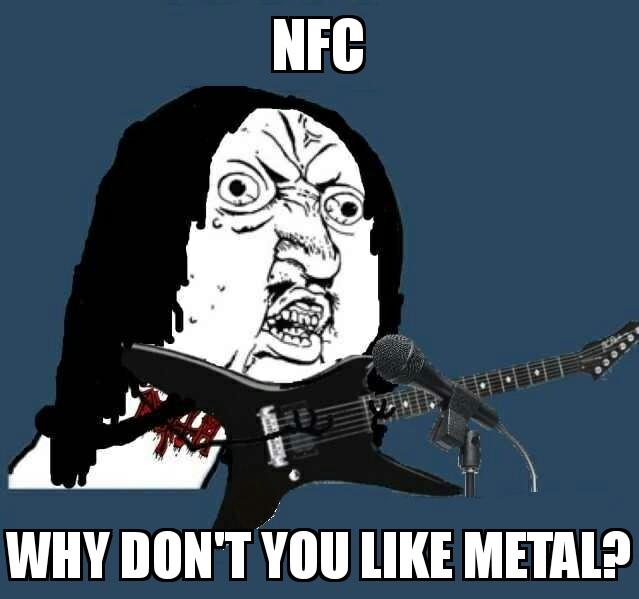
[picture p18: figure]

### Détruire correctement votre KeyDuino

KeyDuino vous permettra de prototyper bon nombre de projets. Néanmoins, dans la précipitation, certaines erreurs classiques peuvent endommager, voire détruire votre KeyDuino.
Voici une liste non-exhaustive des erreurs potentielles :

Court circuits :
- Faire un court-circuit entre une entrée/sortie et la masse/l’alimentation
- Faire un court-circuit entre deux entrées/sorties avec chacune un état différent
- Faire un court-circuit entre l’alimentation 5v/3.3v/VIN et la masse

Surtension :
- Appliquer une tension supérieure à 5.5volts sur une entrée/sortie
- Appliquer une tension supérieure à 5 volts sur la pin 5volts
- Appliquer une tension supérieure à 12 volts sur la pin 12 volts / le connecteur DC

Surconsommation :
- Consommer plus de 40mA par pin
- Consommer plus de 200mA sur l’ensemble des pins
- Consommer plus de 2A sur l’alimentation VIN
- Consommer plus de 500mA sur l’alimentation 5volts
- Consommer plus de 150mA sur l’alimentation 3.3volts

Etonnamment, KeyDuino n’est pas prévu pour fonctionner à des températures extrêmes, des milieux trop humides ou sous des chocs trop importants. Des erreurs classiques telles que mesurer les vibrations à l’intérieur d’un mixer ou la température dans un four peuvent laisser quelques dommages à KeyDuino.

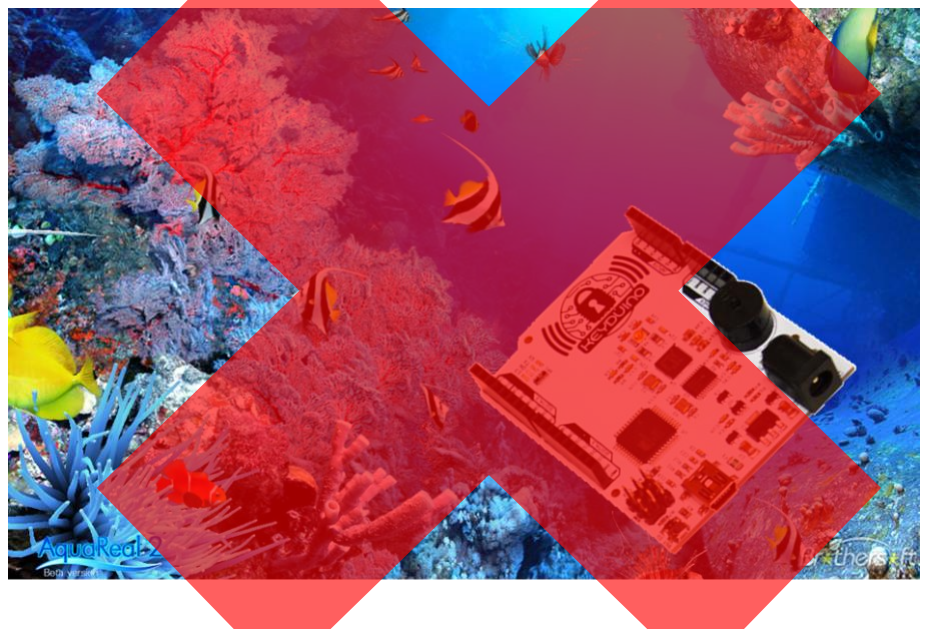
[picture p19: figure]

### Prenez donc soin de votre KeyDuino !

# 3) Initialiser votre KeyDuino

### Installer l’environnement Arduino

Pour commencer à utiliser et programmer votre KeyDuino, vous aurez besoin de l’environnement de développement (IDE) Arduino. Vous pouvez le télécharger ici : https://www.arduino.cc/en/Main/Software Les codes actuels sont développés avec la version 1.6.5 d’Arduino. Si vous débutez avec Arduino, il est recommandé d’utiliser la même version pour éviter tous problèmes.
Décompressez le fichier et installez Arduino.

### Télécharger la bibliothèque KeyDuino

Pour avoir accès aux codes d’utilisations et à la bibliothèque KeyDuino, il faut premièrement la télécharger sur la plateforme GitHub :
https://github.com/CITCEuraRFID/KeyDuino Cliquer sur le bouton « Download ZIP », et une fois téléchargé, l’extraire. Dans le répertoire KeyDuino, vous trouverez divers dossiers, comme hardware, qui contient les schémas électroniques notamment. Copiez simplement le sous-dossier KeyDuino, et collez le dans le répertoire « libraries » d’Arduino.
La bibliothèque est alors installée ! Il n’y a plus qu’à lancer l’IDE Arduino pour pouvoir l’utiliser.

### Télécharger l’application KeyDuino

Pour utiliser l’application Android développée spécialement pour KeyDuino, télécharger l’apk sur la plateforme GitHub.
Vous pouvez également trouver les sources de cette application dans le dossier de la bibliothèque KeyDuino précédemment téléchargé.
Signalons que bien malheureusement, les Apple iPhones ne sont pas compatibles avec KeyDuino ou les tags NFC dans leurs versions actuelles.

### Installer les drivers KeyDuino

Connectez la KeyDuino à un port USB avec le câble fourni. La LED « On » doit s’allumer.

- Windows
Pour Microsoft Windows XP / Seven : http://www.visualmicro.com/post/2012/06/02/Arduino-Leonardo-Windows-Hardware-USB-Installation-Guide.aspx (http://www.visualmicro.com/post/2012/06/02/Arduino-Leonardo-Windows-Hardware-USB-Installation-Guide.aspx)
- Linux
Connectez la KeyDuino. C’est tout.
- Mac OS
La première fois que vous connectez KeyDuino sur un système Mac OS, le "Keyboard Setup Assistant" s’ouvrira. Il n’y a rien à configurer, il vous suffit juste de fermer la fenêtre.

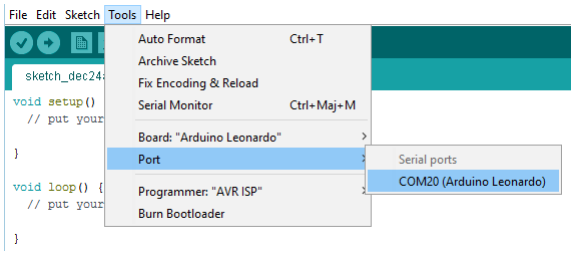
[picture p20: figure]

Erreur : vous rencontrez le message d’erreur suivant

Vérifiez si le port com de la KeyDuino est toujours le même, il peut arriver que le port se déconnecte/reconnecte (principalement pendant le téléversement d’un programme. Puis tentez de rouvrir à nouveau le moniteur série.
Si le problème persiste, débranchez la KeyDuino, fermez le moniteur rebranchez la KeyDuino et retentez de vous connecter.

Erreur : Vous ne voyez pas le port

Solution 1 : Déconnectez votre KeyDuino, fermez l’IDE Arduino. Reconnectez KeyDuino et retentez de sélectionner votre port Solution 2 : Réinstallez les drivers, assurez-vous que KeyDuino est bien reconnu par votre ordinateur

# 4) Débuter avec votre KeyDuino

### Identifier un tag

Sélectionnez votre port sur lequel est connectée votre KeyDuino. Comme la carte possède le même bootloader qu’un Arduino Leonardo, il devrait être identifié comme un Arduino Leonardo.

Normalement, le sketch de base permet de lire le tag NFC fourni et d’afficher les ID obtenus. Pour voir les informations, cliquer sur « Serial Monitor » en haut à droite de la fenêtre Arduino.

Pour cet exemple, votre baudrate doit être à 115200Baud, par défaut, si vous venez de télécharger Arduino, il devrait être à 9600 : Ill faudra donc le changer en bas à droite de Serial Monitor.

Passez à présent l’un des tags fourni prêt de l’antenne de lecture de la KeyDuino, normalement, a plus de 1 centimètre, le buzzer bipe un coup et l’id du tag s’affiche dans la console du moniteur série.

Antenne de lecture


Erreur : Rien ne se passe

Solution 1 : Essayez avec le second tag, si celui-ci réagit, merci de nous contacter pour vous remplacer le tag défectueux. Solution 2 : Eloignez la KeyDuino de toute zone métallique lors de la lecture.
Solution 3 : Testez l’exemple PN532_TEST ; si KeyDuino ne bipe pas, merci de nous contacter (keyduino@outlook.com). Si la KeyDuino bipe, essayez de programmer la KeyDuino avec le programme tag_identification (voir plus bas).

### (Optionnel) Connection de votre antenne déportée

Si vous avez commandé une antenne déportée avec votre KeyDuino, connectez votre câble selon le

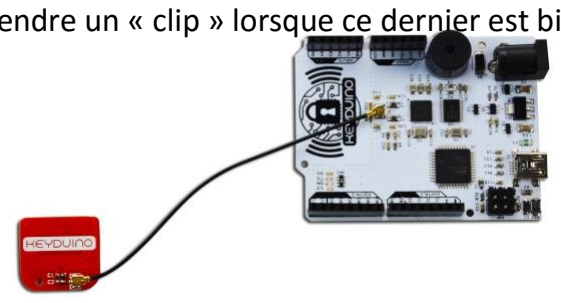
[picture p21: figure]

schéma joint, vous devez entendre un « clip » lorsque ce dernier est bien enfoncé. C’est tout.

### Vous êtes maintenant prêt à utiliser pleinement votre KeyDuino !

Baudrate

Tag ID

Conseils :

- Essayez de ne pas tordre le câble
- Ne connectez/déconnectez pas le câble trop souvent, le connecteur est fragile et doit être manipulé avec soin
- Évitez de le passer entre des endroits métalliques
- Comme pour l’antenne intégrée de la KeyDuino, ne collez pas l’antenne déportée à du métal
- Utilisez des vis plastiques plutôt que métalliques pour fixer l’antenne.
- Sachez que la super glue / le scotch double face marche très bien !

Attention !

Les trois exemples suivant nécessitent l’installation de la bibliothèque NDEF, que vous pouvez trouver à l’adresse suivante : https://github.com/don/NDEF NDEF, pour NFC Data Exchange Format, est un protocole standard de définition des messages transmis via NFC ; un tag avec du contenu NDEF, une fois scanné par un smartphone par exemple, déclenchera sur l'appareil le lancement d'une URL, composera un numéro de téléphone, etc.

# 5) Utiliser votre KeyDuino

Voici maintenant quelques exemples classiques d’utilisation basique de KeyDuino.

### Récupérer l’identifiant (UID) d’un tag

Lors de la manipulation de tags RFID, la première action côté lecteur est généralement de lire l'identifiant unique du tag. L'exemple ci-dessous devrait être compatible avec la plupart des types de tags RFID HF que vous pourriez trouver.

Dans l'IDE Arduino, lancer l'exemple tag_identification :

File > Examples > KeyDuino > tag_identification

Dans cet exemple, la fonction suivante :

keyDuino.readTargetID(uid, &uidLength)

récupère l'UID du tag présenté à l'antenne du KeyDuino, et stocke ce résultat dans la variable uid (et sa taille dans la variable uidLength).

### Lire le contenu d’un tag NDEF

Pour lire les données contenues dans un tag formaté NDEF, lancer l’exemple suivant :

File > Examples > KeyDuino > NDEF > read_tag

Une fois le code envoyé à la carte KeyDuino, ouvrez le Serial Monitor, et passez un tag sur l’antenne de la carte ; vous devriez alors voir s’afficher les données qu’il contient.

### Écrire en NDEF dans un tag

Lancez l’exemple d’écriture dans un tag formaté NDEF :

File > Examples > KeyDuino > NDEF > write_tag

Choisissez un contenu à écrire dans le tag : URL d’un site web, numéro de telephone, adresse mail … Pour que le contenu soit fonctionnel, il faut qu’il soit correctement formaté. Vous pourrez trouver sur Internet comment fonctionne le protocole NDEF.

Vous pouvez ensuite téléverser le programme sur votre KeyDuino, et passer un tag sur l’antenne pour écrire dessus. Testez ensuite avec votre KeyDuino (exemple read_tag) ou un smartphone NFC pour vérifier que le contenu a bien été écrit sur le tag.

### Peer to Peer

Pour vous permettre de prendre en main la communication Peer to Peer (P2P) en NFC, nous avons développé un sketch d’exemple pour la carte, ainsi qu’une application mobile Android. Via un smartphone compatible, vous pourrez ainsi communiquer et interagir avec votre KeyDuino depuis l’application : contrôler des pins, lire les valeurs de tension en sortie …

La démarche à suivre pour vous procurer l’application Android est décrite en Page 8 de ce document. Le sketch d’exemple se trouve à l’emplacement suivant :

File > Examples > KeyDuino > keyduino_android_app

# 6) Utilisez une shield compatible Arduino

### Software

La carte est totalement compatible d’un point de vue software avec une carte Arduino Leonardo. Dès lors, n’importe quel code fonctionnant sur Leonardo fonctionnera sur KeyDuino.

### UART

Pour faire la connexion avec le PN532 en HSU, nous avons utilisé TX (D1) & RX (D0). Néanmoins comme de nombreuses shield Arduino utilisent l’UART, nous avons déporté D14 & D16 de ICSP pour pouvoir les utiliser en Software UART.

Pour utiliser SoftwareSerial, suivez ce lien :
http://www.arduino.cn/reference/SoftwareSerial.html

Dans notre cas, la définition de RX et TX se fera de la façon suivante :

SoftwareSerial mySerial(14, 16);

### SPI

Pour pouvoir placer l’antenne, nous avons repositionné le connecteur ICSP utilisé pour le SPI sur une carte Arduino Leonardo. Pour pouvoir l’utiliser ; il y a deux choix :
- Utiliser des connecteurs entre le ICSP de la shield et celui de KeyDuino (vous ne serez plus en mesure d’utiliser le software UART et le buzzer !).
- Redéfinir le SPI sur d’autre PIN via SoftwareSPI (ex : 13, 12, 11) et effectuer les jonctions avec des connecteurs si c’est nécessaire (quelques shields comme la shield SD n’ont pas de connecteur ICSP).

# 7) (Optionnel) Utiliser la shield relais

Sans alimentation à ses bornes, un relais est bloqué dans sa position Normaly Closed (NC). Dans ce cas, il y a une jonction physique entre le COM et le NC.

En mettant une tension à ses bornes (5V dans notre cas), le courant excite une bobine qui vient commuter le contact. Le contact se fait alors entre COM et Normally Open (NO).

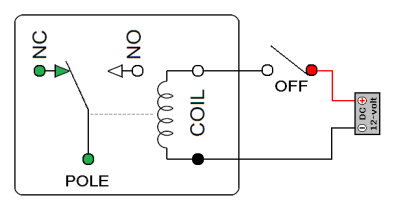
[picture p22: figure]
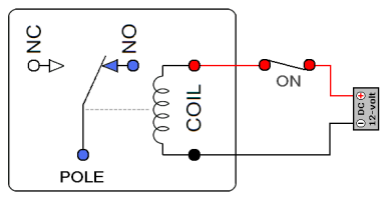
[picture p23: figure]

Dans notre cas, l’interrupteur ON/OFF correspond à la commande de la pin de la KeyDuino. C’est à dire que si la pin est à l’état haut, il y aura jonction entre NO et COM.

Dans la mesure où la shield relais possède 4 relais, cette dernière sera commandée par 4 pins :

Relay1 = KeyDuino pin D7

Relay2 = KeyDuino pin D6

Relay3 = KeyDuino pin D5

Relay4 = KeyDuino pin D4

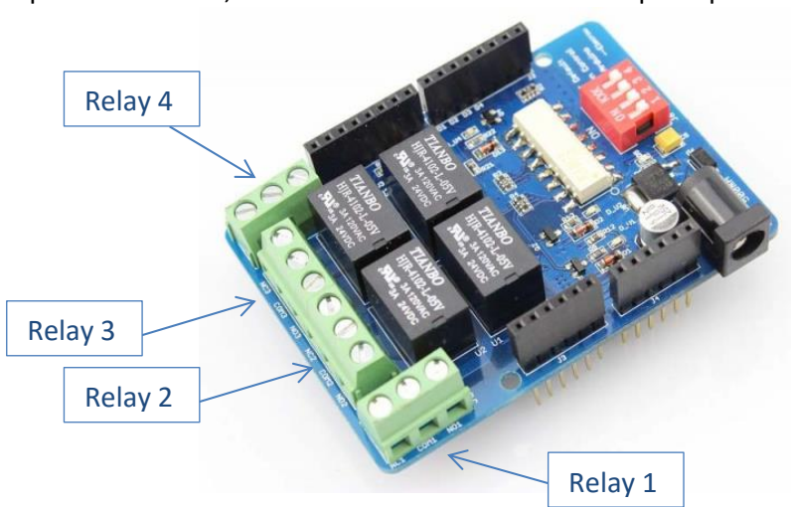
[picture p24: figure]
Relay 4; Relay 3; Relay 2; Relay 1

Vous pouvez trouver un sketch d’utilisation dans les exemples de la bibliothèque KeyDuino :
File > Examples > KeyDuino > relay_shield Cet exemple permet de fermer l’ensemble des contacts des relais sur l’identification d’un badge (selon un UID spécifique, ou quel que soit l’UID). Vous pouvez donc compiler et téléverser votre programme dans la KeyDuino en ayant sélectionné « Arduino Leonardo » et le port Com utilisé.

Pour plus d’informations, consultez le wiki d’ELECROW sur cette shield :

http://www.elecrow.com/wiki/index.php?title=Relay_Shield

Si vous souhaitez que les relais se ferment lors de la détection d’un UID précis, renseignez le chant RIGHT_UID[4], par défaut valant « FF FF FF FF » avec l’UID spécifique souhaité.

# Annexe 1 : Schéma électronique

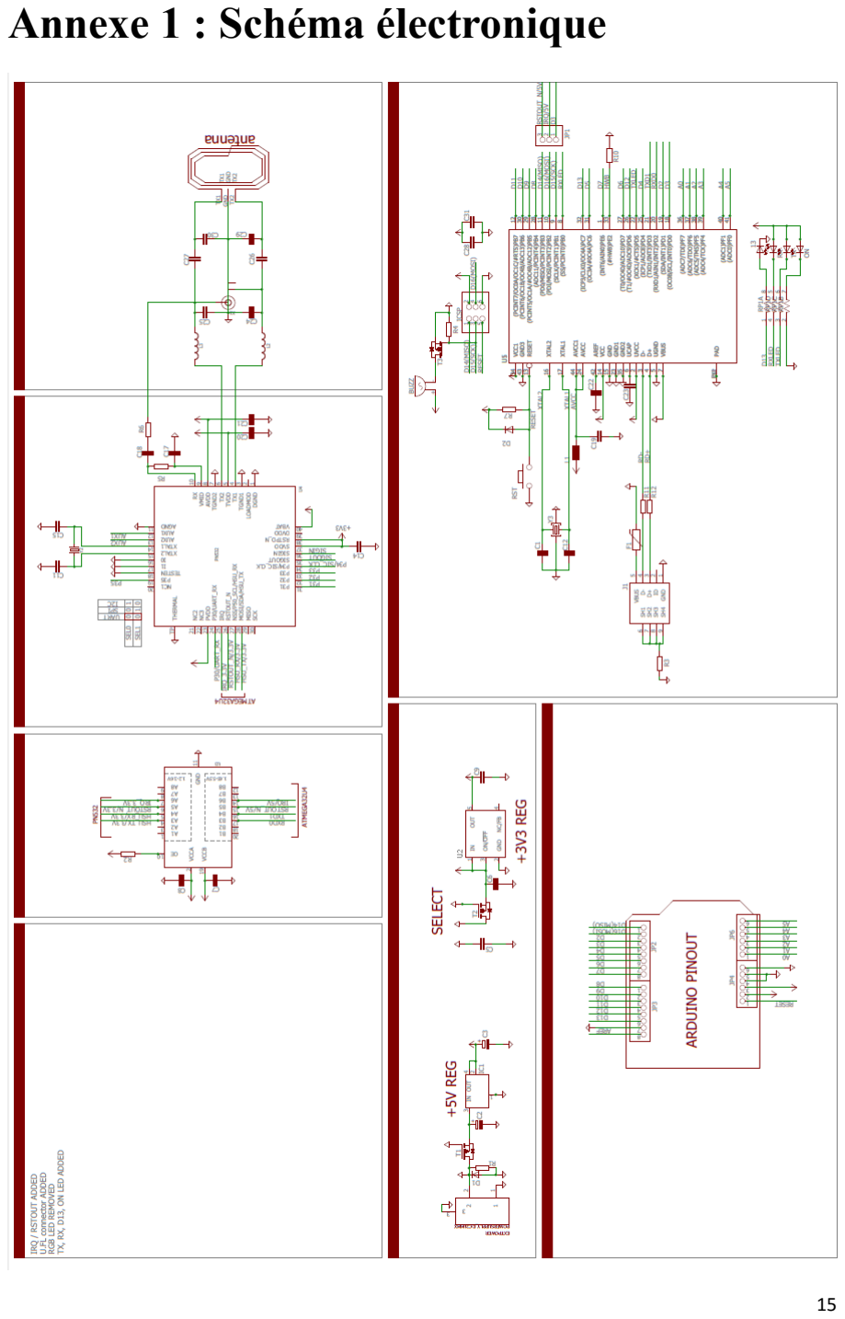
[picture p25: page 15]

# Annexe 2 : Layout

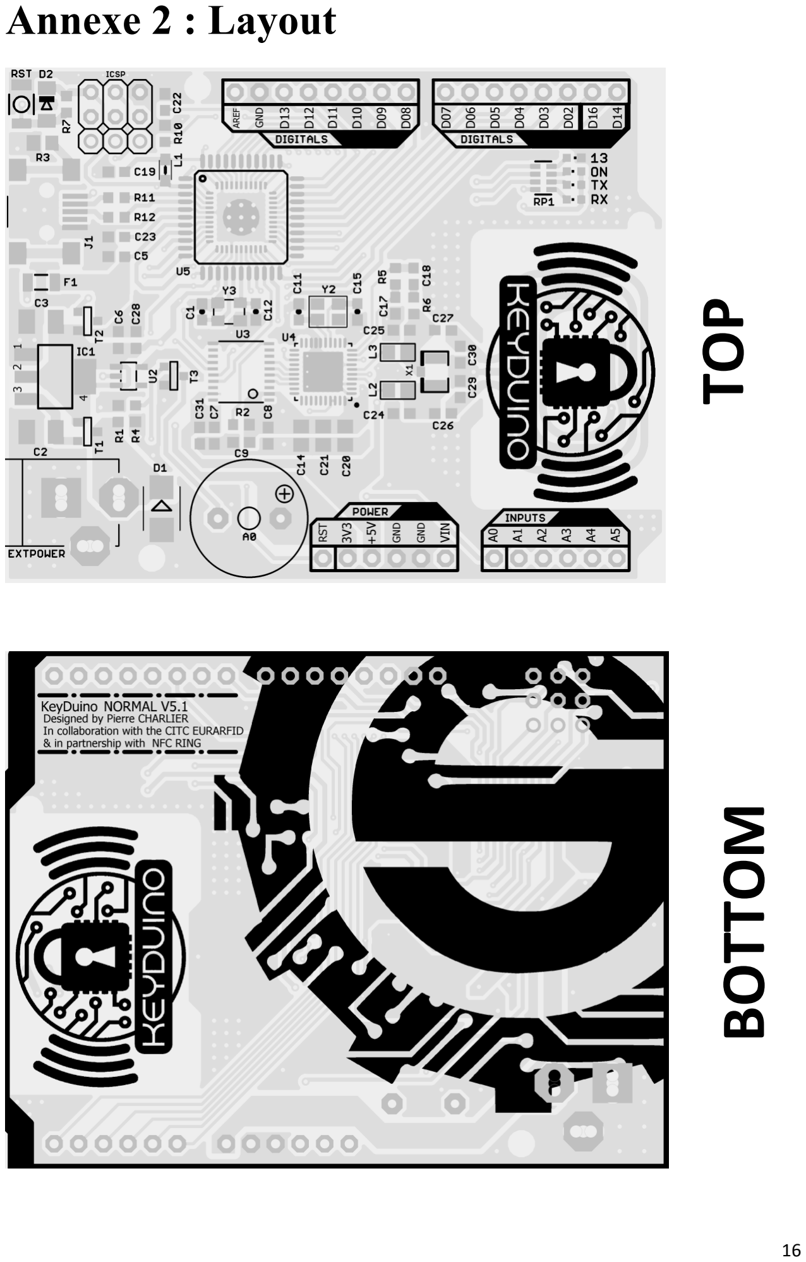
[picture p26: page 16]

# TOP BOTTOM

# Annexe 3 : BOM (Bill Of Material)

Part | QTY | Value | Device | Package | Description | REF

CAPACITOR

C1, C11, C12, C15 | 4 | 22pF | C-EUC0603 | C0603 | Capacitor | capacitor 0603 22pF
C24, C25 | 2 | 220pF | C-EUC0603 | C0603 | Capacitor | capacitor 0603 220pF
C26, C27 | 2 | 2200pF | C-EUC0603 | C0603 | Capacitor | capacitor 0603 2200pF
C18 | 1 | 1nF | C-EUC0603 | C0603 | Capacitor | capacitor 0603 1nF
C29, C30 | 2 | 1,2nF | C-EUC0603 | C0603 | Capacitor | Capacitor 0603 1,2nF
C5, C7, C8, C17, C22, C28, C31 | 7 | 100nF | C-EUC0603 | C0603 | Capacitor | capacitor 0603 100nF
C6, C9, C19, C23 | 4 | 1uF | C-EUC0603 | C0603 | Capacitor | capacitor 0603 1uF
C21 | 1 | 100nF | C-EUC0805 | C0805 | Capacitor | capacitor 0805 100nF
C14, C20 | 2 | 10uF | C-EUC0805 | C0805 | Capacitor | capacitor 0805 10uF
C2 | 1 | 10uF | CPOL-EUSMCB | SMC_B 1206 | CAPACITOR | SMC_B 1206 10uF
C3 | 1 | 22uF | CPOL-EUSMCB | SMC_B 1206 | CAPACITOR | SMC_B 1206 22uF

RESISTOR

R11, R12 | 2 | 22 | R-EU_R0603 | R0603 | RESISTOR | RESISTOR 0603 22
R5 | 1 | 1.0K | R-EU_R0603 | R0603 | RESISTOR | RESISTOR 0603 1K
R6 | 1 | 2.7K | R-EU_R0603 | R0603 | RESISTOR | RESISTOR 0603 2,7K
R1, R2, R4, R7, R10 | 5 | 10K | R-EU_R0603 | R0603 | RESISTOR | RESISTOR 0603 10K
R3 | 1 | 1M | R-EU_R0805 | R0805 | RESISTOR | RESISTOR 0805 1M
RP1 | 1 | 330 | RES4NT | RES4NT | 4 Resistor Array | 4 Resistor Array 330

INDUCTOR

L1 | 1 | MH2029-300Y | WE-CBF_0805 | 805 | SMD EMI Ferrite | MH2029-300Y
L2, L3 | 2 | 560nH | INDUCTOR0805 | 0805@1 | Inductors | inductor 560nH 0805

DIODE & FUSE

D1 | 1 | M7 | DIODE-SMB | SMB | DIODE | SMB M7 (leonardo)
D2 | 1 | CD1206-S01575 | DIODE-MINIMELF | MINIMELF | DIODE | CD1206-S01575
F1 | 1 | 500mA | PTCSMD | PTC-1206 | Resettable Fuse PTC | FUSE 0805 500mA

CONNECTOR & MECHANICAL

ICSP | 1 | ICSP | PINHD-2X3 | 2X03 | PIN HEADER
JP1 | 1 | | PINHD-1X3 | 1X03 | PIN HEADER
JP2 | 1 | | PINHD-1X8CLEANBIG | 1X08-CLEANBIG | PIN HEADER
JP3 | 1 | | PINHD-1X8CLEANBIG | 1X08-CLEANBIG | PIN HEADER
JP4 | 1 | | PINHD-1X6CB | 1X06-CLEANBIG | PIN HEADER
JP6 | 1 | | PINHD-1X6CB | 1X06-CLEANBIG | PIN HEADER
X1 | 1 | | ANTENNA_U.FL | U.FL | U.FL Antenna Connector | u.FL connector
J1 | 1 | USB-MINI-B%C | USB-MINI-B%C | USB-MINI-B_2
EXTPOWER | 1 | POWERSUPPLY_DC21MMX | POWERSUPPLY_DC21MMX | DC-21MM
RST | 1 | RESET | PB157 | 157SW | SKRKAEE010 | 157SW
BUZZ | 1 | F/QMX | F/QMX | F/QMX | | F/QMX (3,3v)

LEDs

RX | 1 | LEDCHIPLED_0603 | CHIPLED_0603 | LED | 0603 LED yellow
TX | 1 | LEDCHIPLED_0603 | CHIPLED_0603 | LED | 0603 LED RED
ON | 1 | LEDCHIPLED_0603 | CHIPLED_0603 | LED | 603 LED green
13 | 1 | LEDCHIPLED_0603 | CHIPLED_0603 | LED | 603 LED blue

IC

U1 | 1 | ATMEGA32U4-XUAU | ATMEGA32U4-XUAU | TQFP44-PAD | ATMEGA32U4-XUAU | ATMEGA32U4-XUAU
U2 | 1 | LP2985-33DBVR | LP2985-XXDBVR33 | SOT23-DBV | ULTRALOW-POWER REGULATORS | LP2985-33DBVR
IC1 | 1 | NCP1117ST50T3G | MC33269ST-3.3T3 | SOT223 | Regulator 800 mA | NCP1117ST50T3G
U3 | 1 | | TXB0108PWR | TSSOP20 | 8-Bit Bi-Directional Level Shifter | TXB0108PWR
U4 | 1 | PN532 | PN532 | HVQFN40-6X6 | PN532 – NFC controller | PN532

CRYSTAL

Y2 | 1 | 27.12MHz | CRYSTALTHIN | CRYSTAL_3.2X2.5 | Crystals | 7B-27,1200MAAJ-T
Y3 | 1 | 16MHz KX-7 | CRYSTAL-3.2-2.5 | CRYSTAL-3.2-2.5 | | 16MHz KX-7

MOSFET

T1 | 1 | PMV48XP | PMOSSOT23 | SOT-23 | MOS FET | PMV48XP
T2 | 1 | FDN340P | PMOSSOT23 | SOT-23 | MOS FET | FDN340P
T3 | 1 BSS123 | PMOSSOT23 | SOT-23 | MOS FET | BSS123

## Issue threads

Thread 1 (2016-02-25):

Problem with Arduino 1.6.7

RayBor, 2016-02-25:
Some users are having troubles using the lib with Arduino IDE 1.6.7

RayBor, 2016-03-01:
Closed issue, problem wasn't in fact directly related to Arduino version, but bad spaces characters in exemples.
See commit https://github.com/CITCEuraRFID/KeyDuino/commit/2dec54d9aa4eae24fb96a70bf9f950e758b0c956

Closed 2016-03-01.

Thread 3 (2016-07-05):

Android app does not work - parse error

hopo28, 2016-07-05:
error that comes up:
Parse Error
There was a problem while parsing the package.

phones tested on:
Samsung galaxy S7 running android 6.0.1
Samsung galaxy S5 running android 6.0.1
Samsung galaxy S3 running android 4.3
Samsung galaxy S2 running android 4.1.2

RayBor, 2016-07-05:
Hi, and thanks for your review.
Could you please be more specific ?
When does exactly this error message appears ?
Thanks

hopo28, 2016-07-05:
Its when i try to install it.
In all cases i made sure that the unknown sources thing was allowed in the
accessibility settings, so its not that :-/

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

RayBor, 2016-07-05:
Plus it tells exactly the problem when it's about unknown sources.

It is quite strange because I can install the app through the APK myself on my Sony Xperia, and it works too on Nexus tablets. Did you try to download the apk again ? Maybe there was a problem with it ...

There are a few sources on the Internet that pretends to know how to solve this problem ...
Check this one : http://www.smarttricks.net/fix-there-is-a-problem-parsing-the-package

Tell me if it works :)

hopo28, 2016-07-05:
yup, tried re-downloading, same error, double checked the unknown sources
thing (under security in marshmallow)

right, done some searching, and there are 4 things that keep coming up;

1-install apps from unknown sources - checked that

2-corrupt apk - downloaded several times so its not that unless the one on
github is corrupt

3-not compatable with my device(s) - possible i suppose, im guessing we
have no proof of it working on an S2,S3,S5,S7 so far?

4-something is incorrect in the manifest - i dont really understand this
but guessing its like a header in the APK, either way, that bit is out of
my control

I'm out of ideas for now.

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

RayBor, 2016-07-05:
Well, I just downloaded the Apk from GitHub, sent it to a Galaxy S5 and had no problem installing it.
So I have no more ideas either :/

But anyway, the app isn't that great ... maybe the world doesn't want you to use that dirt :p
May I know what you need it for ?

hopo28, 2016-07-05:
I was planning on creating a project similar to the demo one; the infinity
coffee table and was looking into using a phone as an interface,
admittedly, i havent taken the keyduino out of the box yet, but was looking
into the app first.

ok, on a whim i replicated what you did... downloaded the apk, then sent to
the phone as oppposed to downloading on the phone itself... it now works!
I imagine there is something up with downloding on the phone.
i see what you mean about the app being a bit lacklustre, do you know of
others that might suit my requirements?

issue appers to be a non-issue :-/

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

RayBor, 2016-07-05:
Then I close it :)

If you want something like the NFC Infinity Table, the KeyDuino app should be enough. But you can also use NXP Chameleon (like in the video) which is lighter.

In any case, this uses Peer-to-peer NFC between the devices, and we seem to have problem with a lot of phones on that. It may be a hardware problem (KeyDuino uses a PN532, and maybe it wants something like it).

So if it's not working with it (AKA you can begin the NFC P2P communication but never finish it) your phone is not compatible.
I don't have a lot of time to work on that and see if the problem is within the library, but I'll keep you posted if any news.

Thanks again for your review, and don't hesitate if you need anything else ;)

Ray

Closed 2016-07-05.

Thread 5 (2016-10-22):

Compiling error

phycmcmv, 2016-10-22:
I get this error when compiling an Arduino program that calls this library:

_KeyDuino.cpp:716:77: warning: narrowing conversion of '(((int)len) + 1)' from 'int' to 'uint8_t {aka unsigned char}' inside { } [-Wnarrowing]_

Being called from the relay_shield example from that is part Keyduino:
https://github.com/CITCEuraRFID/KeyDuino/tree/master/KeyDuino/examples

Any guidance on how to fix this?

RayBor, 2016-10-22:
Hi,

This error is very strange. When I compile the code on my PC I don't have any error.
Plus, this seems to indicate a problem on line 716, character 77 of the KeyDuino.cpp file, but there is nothing on this line in the file, and it's part of a function that has nothing to do with the relay_shield example.

Still, it seems to be only a warning and not an error, so that should'nt prevent you from compiling.
Is'nt there anything else on your compile output ?

Ray

phycmcmv, 2016-10-23:
Thanks Ray - yes, there was this additional error:

...Arduino\libraries\KeyDuino\KeyDuino.cpp:1053:16: error: 'Serial1' was not declared in this scope

     _serial = &Serial1;

                ^_

mrstein, 2016-10-23:
Hi,
Maybe you  didn't select the good board in "tool>board", can you check if you use the correct one (Arduino Leonardo)?

phycmcmv, 2016-10-23:
Thanks - that solved it.

Closed 2016-10-23.

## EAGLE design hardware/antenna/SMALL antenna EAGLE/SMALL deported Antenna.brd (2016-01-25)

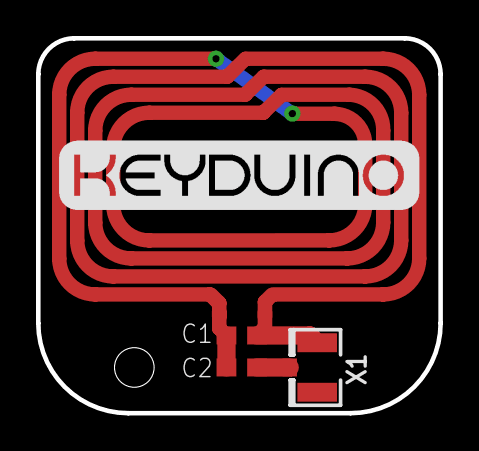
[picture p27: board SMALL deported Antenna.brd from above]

Board: 2 copper layers, 22.4 x 20.8 mm, 4 parts (0 on the bottom side), 3 nets.

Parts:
C1: 390p; C0603
C2: 68p; C0603
U$1: ANT_V7; ANT_13.56_P7
X1: U.FL

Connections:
unnamed: C2.2, X1.3
unnamed: C1.2, U$1.TX2, X1.1, X1.2
unnamed: C1.1, C2.1, U$1.TX1

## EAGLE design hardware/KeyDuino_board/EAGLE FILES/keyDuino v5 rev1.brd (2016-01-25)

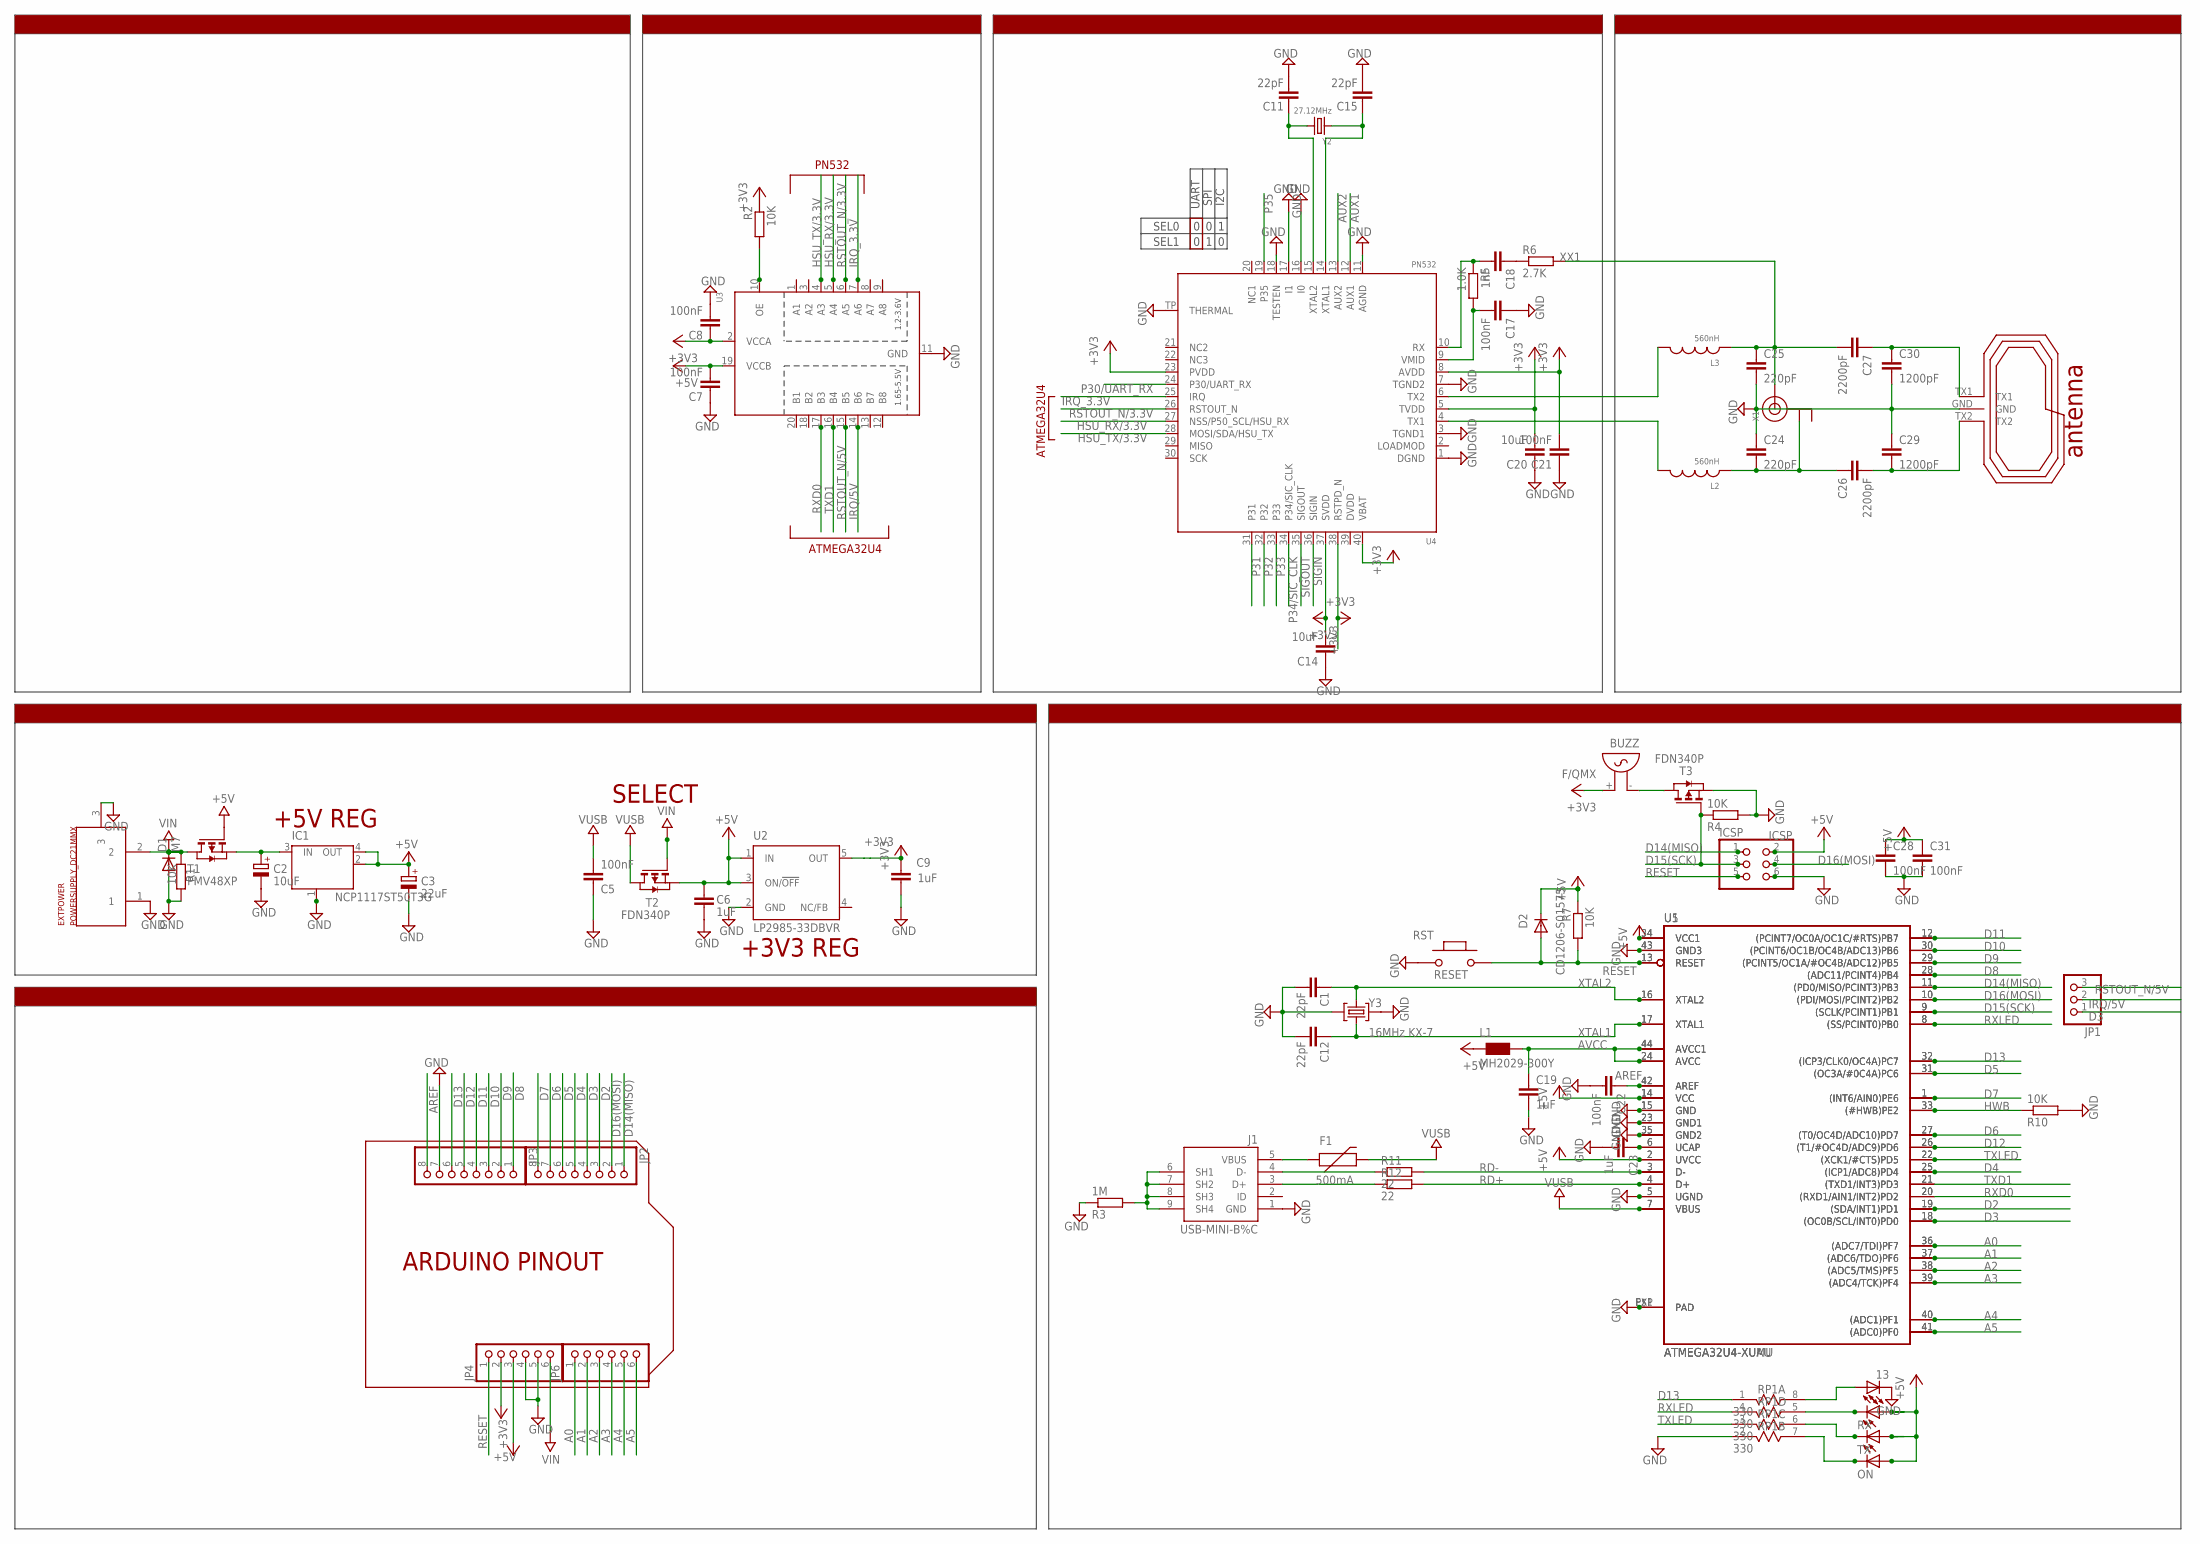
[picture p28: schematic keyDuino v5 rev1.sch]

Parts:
13: LEDCHIPLED_0603; CHIPLED_0603
BUZZ: F/QMX
C1, C11, C12, C15: 22pF; 0603-CAP
C2: 10uF; SMC_B
C3: 22uF; SMC_B
C5, C7, C8, C17, C22, C28, C31: 100nF; C0603
C6, C9, C19, C23: 1uF; C0603
C14, C20: 10uF; C0805
C18: 1nF; C0603
C21: 100nF; C0805
C24, C25: 220pF; C0603
C26, C27: 2200pF; C0603
C29, C30: 1200pF; C0603
D1: M7; SMB
D2: CD1206-S01575; MINIMELF
EXTPOWER: POWERSUPPLY_DC21MMX; POWERSUPPLY_DC-21MM
F1: 500mA; PTC-1206
IC1: NCP1117ST50T3G; SOT223
ICSP: ICSP; 2X03
J1: USB-MINI-B%C; USB-MINI-B_2
JP1: PINHD-1X3; 1X03
JP2, JP3: PINHD-1X8CLEANBIG; 1X08-CLEANBIG
JP4, JP6: PINHD-1X6CB; 1X06-CLEANBIG
L1: MH2029-300Y; 0805
L2, L3: 560nH; 0805@1
ON: LEDCHIPLED_0603; CHIPLED_0603
R1, R2, R4, R7, R10: 10K; R0603
R3: 1M; R0805
R5: 1.0K; R0603
R6: 2.7K; R0603
R11, R12: 22; R0603
RP1: 330; RES4NT
RST: RESET; 157SW
RX: LEDCHIPLED_0603; CHIPLED_0603
T1: PMV48XP; SOT-23
T2, T3: FDN340P; SOT-23
TX: LEDCHIPLED_0603; CHIPLED_0603
U1: ATMEGA32U4-XUAU; TQFP44-PAD
U2: LP2985-33DBVR; SOT23-DBV
U3: TXB0108PWR; TSSOP20
U4: PN532; HVQFN40-6X6
U5: ATMEGA32U4-XUMU; QFN44ML7X7
U$1: ANT_V3; ANT_13.56_P4
X1: ANTENNA_U.FL; U.FL
Y2: 27.12MHz; CRYSTAL_3.2X2.5
Y3: 16MHz KX-7; CRYSTAL-3.2-2.5

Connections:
+3V3: BUZZ.+ (2), C8.1, C9.2, C14.2, C20.2, C21.2, JP4.2, R2.1, U2.5 (OUT), U3.2 (VCCA), U4.5 (TVDD), U4.8 (AVDD), U4.23 (PVDD), U4.37 (SVDD), U4.38 (RSTPD_N), U4.40 (VBAT)
+5V: C3.+, C6.2, C7.2, C28.1, C31.1, D2.C, IC1.2 (OUT), IC1.4 (OUT), ICSP.2, JP4.3, L1.1, ON.A, R7.1, RX.A, T1.3 (G), T2.2 (S), TX.A, U1.2 (UVCC), U1.14 (VCC), U1.34 (VCC1), U2.1 (IN), U2.3 (ON/!OFF), U3.19 (VCCB), U5.2 (UVCC), U5.14 (VCC), U5.34 (VCC1)
A0: JP6.1, U1.36 ((ADC7/TDI)PF7), U5.36 ((ADC7/TDI)PF7)
A1: JP6.2, U1.37 ((ADC6/TDO)PF6), U5.37 ((ADC6/TDO)PF6)
A2: JP6.3, U1.38 ((ADC5/TMS)PF5), U5.38 ((ADC5/TMS)PF5)
A3: JP6.4, U1.39 ((ADC4/TCK)PF4), U5.39 ((ADC4/TCK)PF4)
A4: JP6.5, U1.40 ((ADC1)PF1), U5.40 ((ADC1)PF1)
A5: JP6.6, U1.41 ((ADC0)PF0), U5.41 ((ADC0)PF0)
AREF: C22.1, JP3.8, U1.42 (AREF), U5.42 (AREF)
AUX1: U4.12 (AUX1)
AUX2: U4.13 (AUX2)
AVCC: C19.1, L1.2, U1.24 (AVCC), U1.44 (AVCC1), U5.24 (AVCC), U5.44 (AVCC1)
B1: 13.A, RP1.8 (2)
CON1: C24.2, C26.1, L2.1, X1.1 (GND)
D2: JP2.3, U1.19 ((SDA/INT1)PD1), U5.19 ((SDA/INT1)PD1)
D3: JP1.1, JP2.4, U1.18 ((OC0B/SCL/INT0)PD0), U5.18 ((OC0B/SCL/INT0)PD0)
D4: JP2.5, U1.25 ((ICP1/ADC8)PD4), U5.25 ((ICP1/ADC8)PD4)
D5: JP2.6, U1.31 ((OC3A/#0C4A)PC6), U5.31 ((OC3A/#0C4A)PC6)
D6: JP2.7, U1.27 ((T0/OC4D/ADC10)PD7), U5.27 ((T0/OC4D/ADC10)PD7)
D7: JP2.8, U1.1 ((INT6/AIN0)PE6), U5.1 ((INT6/AIN0)PE6)
D8: JP3.1, U1.28 ((ADC11/PCINT4)PB4), U5.28 ((ADC11/PCINT4)PB4)
D9: JP3.2, U1.29 ((PCINT5/OC1A/#OC4B/ADC12)PB5), U5.29 ((PCINT5/OC1A/#OC4B/ADC12)PB5)
D10: JP3.3, U1.30 ((PCINT6/OC1B/OC4B/ADC13)PB6), U5.30 ((PCINT6/OC1B/OC4B/ADC13)PB6)
D11: JP3.4, U1.12 ((PCINT7/OC0A/OC1C/#RTS)PB7), U5.12 ((PCINT7/OC0A/OC1C/#RTS)PB7)
D12: JP3.5, U1.26 ((T1/#OC4D/ADC9)PD6), U5.26 ((T1/#OC4D/ADC9)PD6)
D13: JP3.6, RP1.1, U1.32 ((ICP3/CLK0/OC4A)PC7), U5.32 ((ICP3/CLK0/OC4A)PC7)
D14(MISO): ICSP.1, JP2.1, U1.11 ((PD0/MISO/PCINT3)PB3), U5.11 ((PD0/MISO/PCINT3)PB3)
D15(SCK): ICSP.3, R4.1, T3.3 (G), U1.9 ((SCLK/PCINT1)PB1), U5.9 ((SCLK/PCINT1)PB1)
D16(MOSI): ICSP.4, JP2.2, U1.10 ((PDI/MOSI/PCINT2)PB2), U5.10 ((PDI/MOSI/PCINT2)PB2)
G1: RP1.5 (2), RX.C
GND: 13.C, C1.1, C2.-, C3.-, C5.1, C6.1, C7.1, C8.2, C9.1, C11.1, C12.1, C14.1, C15.1, C17.1, C19.2, C20.1, C21.1, C22.2, C23.2, C24.1, C25.2, C28.2, C29.1, C30.2, C31.2, D1.A, EXTPOWER.1, EXTPOWER.3, IC1.1 (GND/ADJ), ICSP.6, J1.1 (GND), JP3.7, JP4.4, JP4.5, R1.1, R3.1, R4.2, R10.2, RP1.2 (1), RST.1, T3.2 (S), U1.5 (UGND), U1.15 (GND), U1.23 (GND1), U1.35 (GND2), U1.43 (GND3), U1.P$1 (PAD), U2.2 (GND), U3.11 (GND), U4.1 (DGND), U4.3 (TGND1), U4.7 (TGND2), U4.11 (AGND), U4.16 (I0), U4.17 (I1), U4.18 (TESTEN), U4.TP (THERMAL), U5.5 (UGND), U5.15 (GND), U5.23 (GND1), U5.35 (GND2), U5.43 (GND3), U5.EXP (PAD), U$1.GND, Y3.2 (GND), Y3.4 (GND)
HSU_RX/3.3V: U3.5 (A4), U4.27 (NSS/P50_SCL/HSU_RX)
HSU_TX/3.3V: U3.4 (A3), U4.28 (MOSI/SDA/HSU_TX)
HWB: R10.1, U1.33 ((#HWB)PE2), U5.33 ((#HWB)PE2)
IRQ/5V: JP1.2, U3.14 (B6)
IRQ_3.3V: U3.7 (A6), U4.25 (IRQ)
unnamed: BUZZ.- (1), T3.1 (D)
unnamed: F1.1, J1.5 (VBUS)
unnamed: J1.6 (SH1), J1.7 (SH2), J1.8 (SH3), J1.9 (SH4), R3.2
unnamed: C18.1, R6.1
unnamed: L2.2, U4.4 (TX1)
unnamed: L3.2, U4.6 (TX2)
unnamed: ON.C, RP1.7 (2)
unnamed: J1.4 (D-), R11.1
unnamed: J1.3 (D+), R12.1
unnamed: C2.+, IC1.3 (IN), T1.2 (S)
unnamed: R2.2, U3.10 (OE)
unnamed: C15.2, U4.14 (XTAL1), Y2.1
unnamed: C11.2, U4.15 (XTAL2), Y2.2
unnamed: C17.2, R5.2, U4.9 (VMID)
unnamed: C18.2, R5.1, U4.10 (RX)
P30/UART_RX: U4.24 (P30/UART_RX)
P31: U4.31
P32: U4.32
P33: U4.33
P34/SIC_CLK: U4.34 (P34/SIC_CLK)
P35: U4.19 (P35)
R1: RP1.6 (2), TX.C
RD+: R12.2, U1.4 (D+), U5.4 (D+)
RD-: R11.2, U1.3 (D-), U5.3 (D-)
RESET: D2.A, ICSP.5, JP4.1, R7.2, RST.2, U1.13 (RESET), U5.13 (RESET)
RSTOUT_N/3.3V: U3.6 (A5), U4.26 (RSTOUT_N)
RSTOUT_N/5V: JP1.3, U3.15 (B5)
RXD0: U1.20 ((RXD1/AIN1/INT2)PD2), U3.17 (B3), U5.20 ((RXD1/AIN1/INT2)PD2)
RXLED: RP1.4 (1), U1.8 ((SS/PCINT0)PB0), U5.8 ((SS/PCINT0)PB0)
SIGIN: U4.36 (SIGIN)
SIGOUT: U4.35 (SIGOUT)
TX1_ANTENNA: C26.2, C29.2, U$1.TX2
TX2_ANTENNA: C27.1, C30.1, U$1.TX1
TXD1: U1.21 ((TXD1/INT3)PD3), U3.16 (B4), U5.21 ((TXD1/INT3)PD3)
TXLED: RP1.3 (1), U1.22 ((XCK1/#CTS)PD5), U5.22 ((XCK1/#CTS)PD5)
UCAP: C23.1, U1.6 (UCAP), U5.6 (UCAP)
VIN: D1.C, EXTPOWER.2, JP4.6, R1.2, T1.1 (D), T2.3 (G)
VUSB: C5.2, F1.2, T2.1 (D), U1.7 (VBUS), U5.7 (VBUS)
XTAL1: C12.2, U1.17 (XTAL1), U5.17 (XTAL1), Y3.1 (C1)
XTAL2: C1.2, U1.16 (XTAL2), U5.16 (XTAL2), Y3.3 (C2)
XX1: C25.1, C27.2, L3.1, R6.2, X1.3 (SIGNAL)

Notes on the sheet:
ATMEGA32U4
+3V3 REG
SEL0
SEL1
UART
SPI
I2C
SELECT
SUPPLYs
+5V REG
convertisseur de niveau
PN532
ACCORDING CIRCUIT
PINOUT
ARDUINO PINOUT
MOD

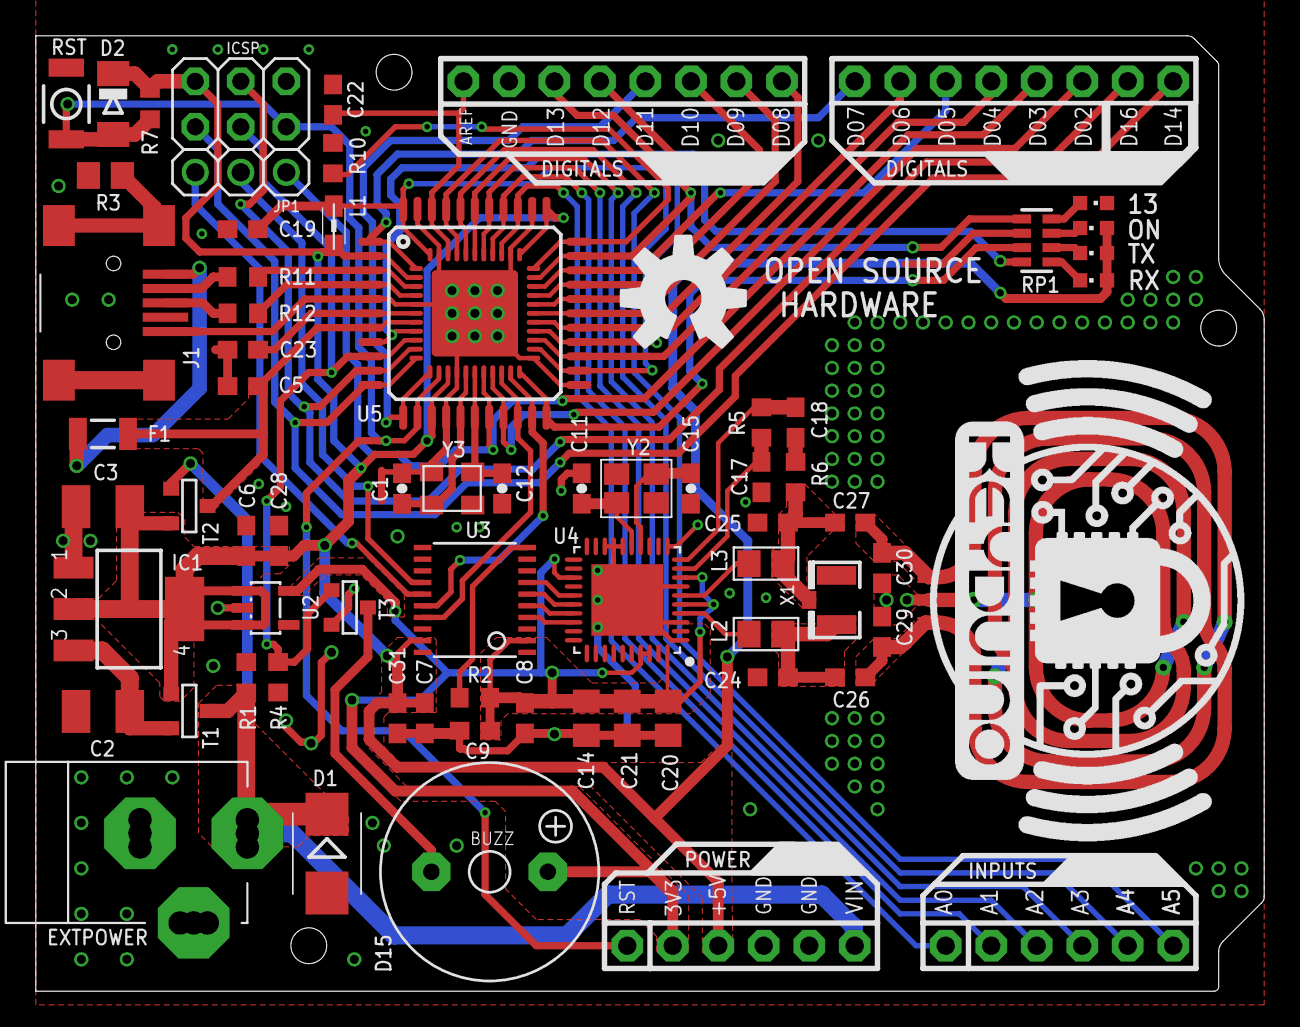
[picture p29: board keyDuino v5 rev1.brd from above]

Board: 2 copper layers, 68.6 x 53.3 mm, 72 parts (0 on the bottom side), 67 nets.

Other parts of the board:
U$2: OSHW-LOGO-L

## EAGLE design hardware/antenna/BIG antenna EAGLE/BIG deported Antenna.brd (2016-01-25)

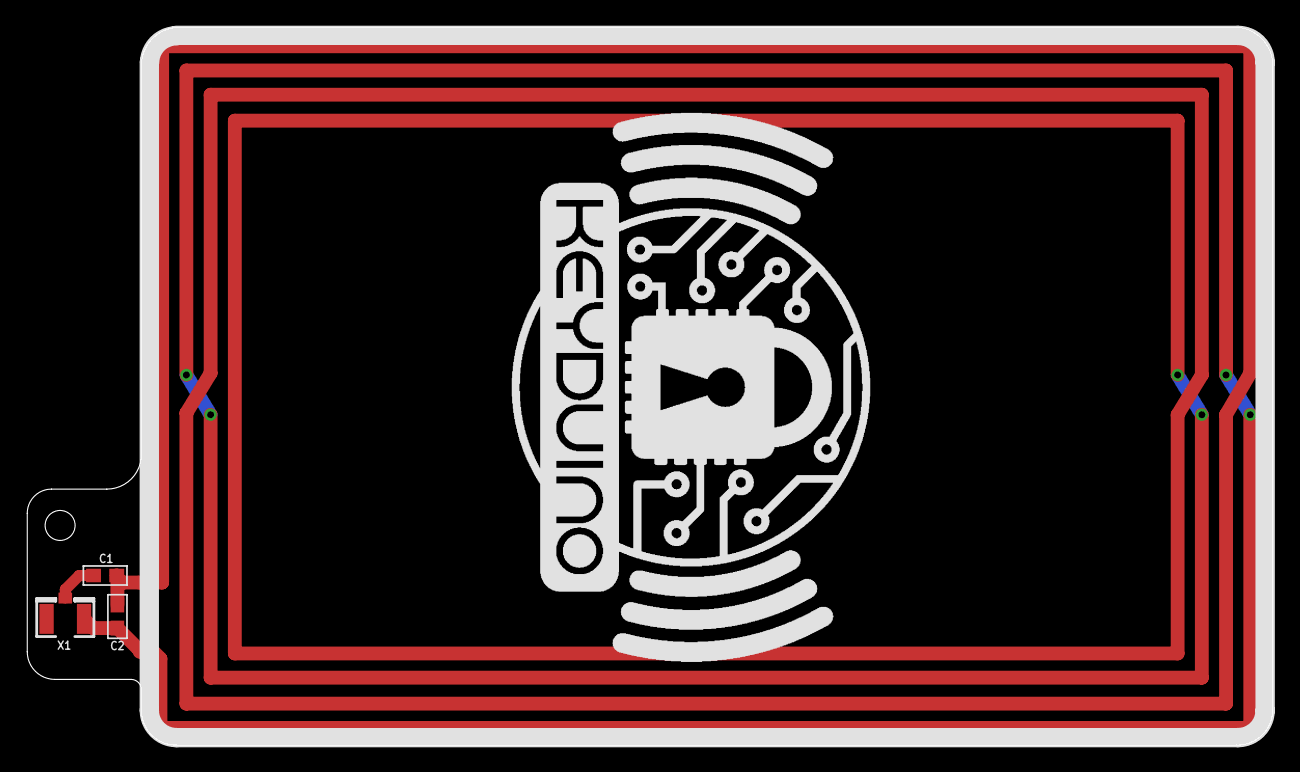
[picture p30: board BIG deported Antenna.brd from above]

Board: 2 copper layers, 91.4 x 52.7 mm, 4 parts (0 on the bottom side), 3 nets.

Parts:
C1, C2: 22p; 0603
U$1: KEYDUINO_DEPORTED_ANTENNA
X1: U.FL

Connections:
ANT1-TX1: C1.1, X1.3
unnamed: C2.1, U$1.TX2, X1.1, X1.2
TX2_ANTENNA: C1.2, C2.2, U$1.TX1

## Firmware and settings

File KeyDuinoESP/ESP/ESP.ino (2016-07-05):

/*
   ESP-8266 that connects to a WiFi network and chats with an MQTT server (publish & subscribe)
   It checks if the NFC tag ID is authorized and sends the response to the KeyDuino in order to enable actions... or not...
   Wakes up periodically (configure SLEEP_DELAY_IN_SECONDS accordingly).
   If you wish to enable deep_sleep for the ESP:
   Hookup guide:
  - connect D0 pin to RST pin in order to enable the ESP-8266 to wake up periodically
*/

#include <SoftwareSerial.h>
#include <ESP8266WiFi.h>
#include <PubSubClient.h>
#include <Streaming.h>

//#define SLEEP_DELAY_IN_SECONDS   30

// defines for serial communication to Keyduino
#define RX  4
#define TX  5

// defines and variable for access control
#define ACCESS_DENIED    0
#define ACCESS_GRANTED   1
int access = 0;
String NFCID;
char message_buff[100];

// WiFi setup
const char* ssid = "<YOUR WIFI NETWORK SSID>";
const char* password = "YOUR WIFI PASSWORD";

// MQTT setup
const char* mqtt_server = "<YOUR MQTT SERVER ADDRESS>";
const char* mqtt_username = "<A USERNAME>";            // used while connecting to the broker
const char* mqtt_password = "";                        // leave empty if not needed
const String mqtt_topic_syntax = "keyduino/nfc/";      // the first part of the MQTT topic, the mac address of the ESP is added automaticaly when creating the full topic
char* mqtt_topic = "";
char* mqtt_topic_access = "";
char* mqtt_payload = "";
boolean retained = false;

WiFiClient espClient;
PubSubClient client(espClient);

SoftwareSerial mySerial(RX, TX);  // RX, TX to be defined

void setup() {
  // setup serial port
  Serial.begin(115200);

  // setup WiFi
  setup_wifi();
  client.setServer(mqtt_server, 1883);
  client.setCallback(callback);

  // setup UART
  Serial.println("Initializing UART connection...");
  mySerial.begin(9600);
  mySerial.setTimeout(10);

  // create mqtt_topic with MAC address
  mqtt_topic = createMqtt_topic(mqtt_topic_syntax);
  mqtt_topic_access = createMqtt_topic_access(mqtt_topic_syntax);
  Serial << "MQTT Topic generated (dialog): " << mqtt_topic << endl;
  Serial << "MQTT Topic generated (access control): " << mqtt_topic_access << endl;

  // sending "connected" to broker
  client.publish(mqtt_topic, "connected", retained);
}

void loop() {
  Serial << endl << "---------- Starting LOOP ----------" << endl;
  destroyAccess();
  NFCID = "";

  getID_Keyduino();

  if (!client.connected()) {
    reconnect();
  }

  sendID_MQTT();
  
  verifyAccess();

  //Serial << "Closing MQTT connection..." << endl;
  //client.disconnect();

  //Serial << "Closing WiFi connection..." << endl;
  //WiFi.disconnect();

  delay(100);

  //Serial << "Entering deep sleep mode for " << SLEEP_DELAY_IN_SECONDS << " seconds..." << endl;
  //ESP.deepSleep(SLEEP_DELAY_IN_SECONDS * 1000000, WAKE_RF_DEFAULT);
  //ESP.deepSleep(10 * 1000, WAKE_NO_RFCAL);
  delay(500);   // wait for deep sleep to happen

  Serial << "---------- Ending LOOP ----------" << endl;
}

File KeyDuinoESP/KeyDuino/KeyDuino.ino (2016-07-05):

/*
 * The KeyDuino reads an NFC tag and sends the tag ID to the ESP in serial communication
 * The tag ID is then read by the ESP and sent to the MQTT broker to check for permissions (server side) 
 * The ESP sends back to the KeyDuino 0 or 1 depending on the authorization
 */
 
#include "KeyDuino.h"
#include <SoftwareSerial.h>
#include <FastLED.h>
#define NUM_LEDS 4
#define DATA_PIN 13
#define BRIGHTNESS 255
CRGB leds[NUM_LEDS];

KeyDuino keyDuino;
#define RX 9
#define TX 8
SoftwareSerial mySerial(RX, TX);  //RX, TX to be defined
uint8_t uid[] = { 0, 0, 0, 0, 0, 0, 0 };
uint8_t uidLength;
int i = 0 ;

void setup() {
  Serial.begin(9600);
  mySerial.begin(9600);
  keyDuino.begin();
  FastLED.addLeds<WS2811, DATA_PIN, GRB>(leds, NUM_LEDS);
  FastLED.setBrightness( BRIGHTNESS );
}

void validate() {
  while (!mySerial.available())  sinelon(0, 255, 255);
  int access = mySerial.read();
  Serial.println(access);

  if (access == 49) {
    keyDuino.buzz(20);
    Color_ALL(0, 255, 0);
    Serial.print("ACCESS GRANTED");
  }
  else if (access == 48) {
    keyDuino.buzz(20);
    delay(250);
    keyDuino.buzz(20);
    Color_ALL(255, 0, 0);
    Serial.print("ACCESS DENIED");
  }
}

String get_ID() {
  uint8_t success = 0;
  String readID;
  while (!success) {
    success = keyDuino.readTargetID(PN532_MIFARE_ISO14443A, uid, &uidLength);
    Color_wait(255, 255, 255);
  }
  readID = keyDuino.convertUintToString(uid, uidLength);
  return (readID);
}

void loop() {
  String readID = get_ID();
  Serial.println("Tag found: ");
  Serial.println(readID);
  mySerial.print(readID);
  validate();
  delay(2000);
  Color_ALL(0, 0, 0);
}

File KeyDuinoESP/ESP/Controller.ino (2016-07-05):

/********** Controller functions **********/

String getID_Keyduino() {
  while (!mySerial.available()) {
    Serial << ".";
    delay(100);
  }
  NFCID = mySerial.readString();
  if (NFCID != "") {
    Serial << endl;
    Serial << "Reading tag ID: " << NFCID << endl;
    return NFCID;
  } else {
    return getID_Keyduino();
  }
}

void sendID_MQTT() {
  if (NFCID != "") {
    // send id to the serial console
    Serial << "Sending ID to MQTT broker: " << NFCID << endl;
    // send id to the MQTT topic
    mqtt_payload = strToChar(NFCID);
    client.publish(mqtt_topic, mqtt_payload, retained);
  }
  client.loop();
}

boolean verifyAccess() {
  client.loop();

  if (access == ACCESS_GRANTED) {
    Serial << "You are authorized !" << endl;
    Serial << "Sending 1 to Keyduino" << endl;
    mySerial.print(1);
    Serial << "Closing MQTT connection..." << endl;
    return true;
  }
  if (access == ACCESS_DENIED) {
    Serial << "You are not authorized !" << endl;
    Serial << "Sending 0 to Keyduino" << endl;
    mySerial.print(0);
    Serial << "Closing MQTT connection..." << endl;
    return false;
  }
}

void destroyAccess() {
  access = ACCESS_DENIED;
}

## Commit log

2016-01-15 Removes debugs prints and adds comments
2016-01-19 Add mifare classic reset example and change methods place.
    [KeyDuino.cpp, KeyDuino.h, mifareclassic_reset.ino]
2016-01-25 Add hardware files
    [BIG deported Antenna.brd, BIG deported Antenna.sch, SMALL deported Antenna.brd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]
2016-01-25 Add relay shield example.
2016-02-09 Add reauthentication if failure.
    [KeyDuino.cpp]
2016-02-19 Include buzzing function in KeyDuino.cpp
    [KeyDuino.cpp, KeyDuino.h, tag_identification.ino]
2016-02-19 Remove buzzing old declaration in example.
    [nfc_unlock.ino]
2016-03-01 Correct typos in exemples.
    [KeyDuino.h, hce_unlock.ino, mifareclassic_read_card.ino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]
2016-03-07 Add KeyDuino pinout control sketch, to be used with KeyDuino Android Application. This is just an example sketch, not optimized. It just shows the way to communicate with the board and pins. This als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
2016-03-14 Add support for recent version of Arduino.
2016-03-17 Add example to read a NDEF message coming from a NFC active device.
2016-03-22 Trying exchanging APDU with ISO14443B cards. Not working yet, but soon ;)
    [KeyDuino.cpp, KeyDuino.h]
2016-03-30 Add tag enlisting when reading ID. Not sure, but shouldn't be a problem.
    [KeyDuino.cpp]
2016-06-15 Added charlier_case stl files
    [KeyDuino case5.STL, top KeyDuino case.STL]
2016-06-15 Add ray_case scad and stl files
    [leonardo_case_base_v1_2_ray.scad, leonardo_case_base_v1_2_ray_bin.stl, leonardo_case_lid_v1_2_ray.scad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]
2016-07-05 Solve problem with P2P : with some device, it worked only with debug mode ... that may be due to a need for delay.
2016-07-05 Optimize reactivation of tags when authentication failed
    [KeyDuino.cpp, KeyDuino.h]
2016-07-05 Reorder broker connexion verification after checking for a tag
    [ESP.ino]

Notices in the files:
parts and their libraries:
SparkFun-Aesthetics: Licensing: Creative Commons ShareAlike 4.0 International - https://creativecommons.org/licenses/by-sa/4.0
